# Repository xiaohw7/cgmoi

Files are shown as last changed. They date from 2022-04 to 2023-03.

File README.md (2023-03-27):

# CGMOI User Guide

## Overview

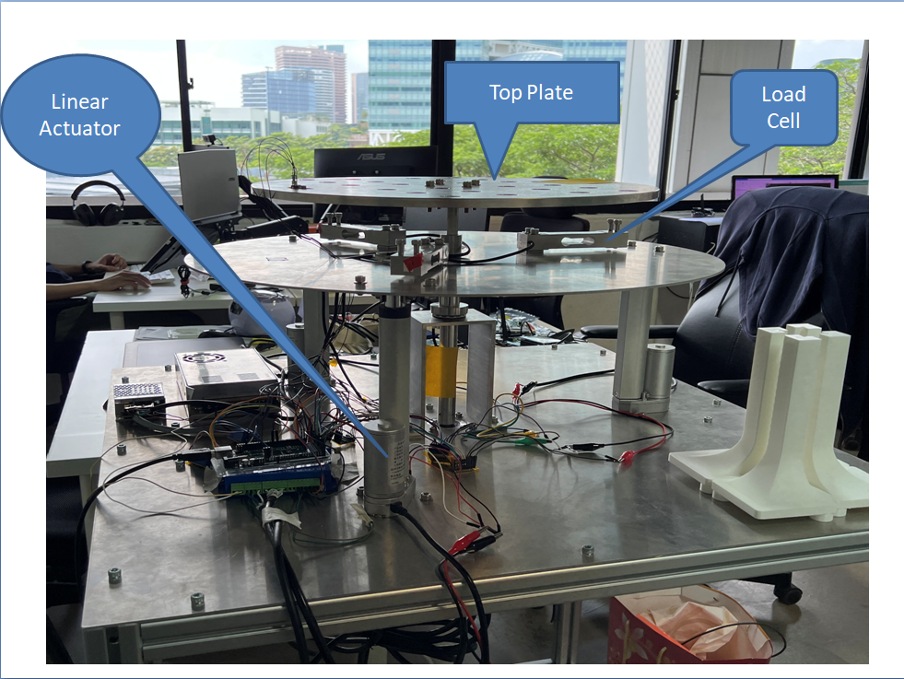
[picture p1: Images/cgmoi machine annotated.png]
cgmoi machine


The CGMOI machine is one that is capable of measuring the Centre of Gravity (CG) and Moment Of Inertia (MOI) of a nano-satellite while satellite is mounted on the top plate as shown in picture below.

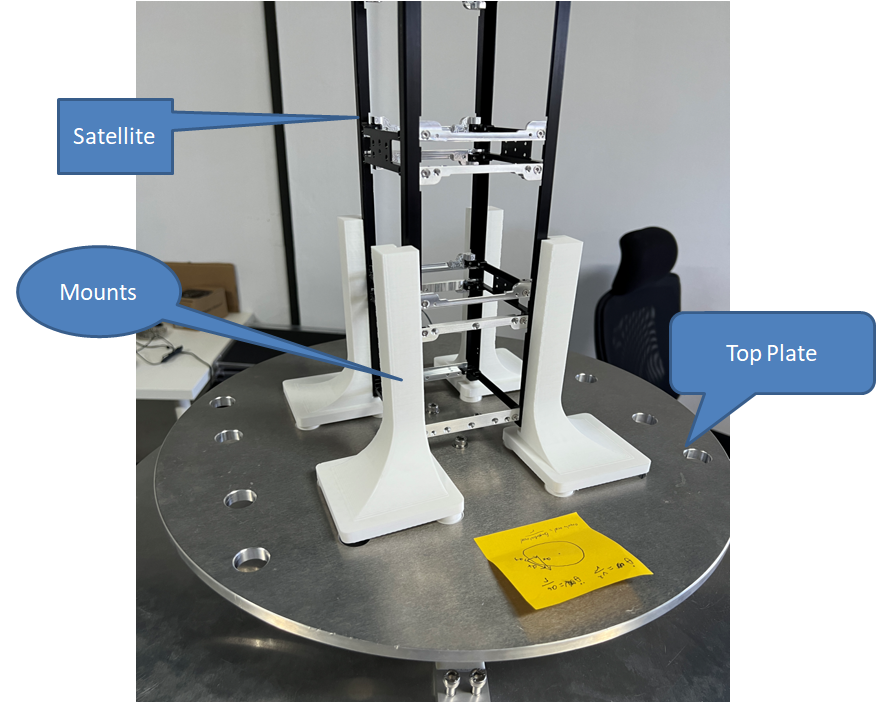
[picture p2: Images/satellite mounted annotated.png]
satellite mounted


The concept of this machine is based on [this research paper](https://github.com/xiaohw7/cgmoi/blob/main/applsci-08-00104.pdf) done by researchers from ZheJiang University. It uses 3 load cells in a circle spaced 120 degrees apart to measure CG and a gyroscope to measure acceleration which in turn can be used to obtain MOI.

The machine also includes a stepper motor that spins the top plate, and linear actuators to raise and lower the load cells in order to measure CG.

The stepper motor, linear actuator, gyroscope, load cells and other components are controlled by and wired to an Arduino mega board. The Arduino could then be plugged into a laptop running the Arduino IDE where code could be uploaded to run the CGMOI machine.

Each load cell is marked load cell 1/2/3 on the load cell itself. Linear actuator 1/2/3 correspond to load cell 1/2/3. i.e. linear actuator 1 is directly below load cell 1.

## Components of the CGMOI Machine

- HX711 analog to digital converter
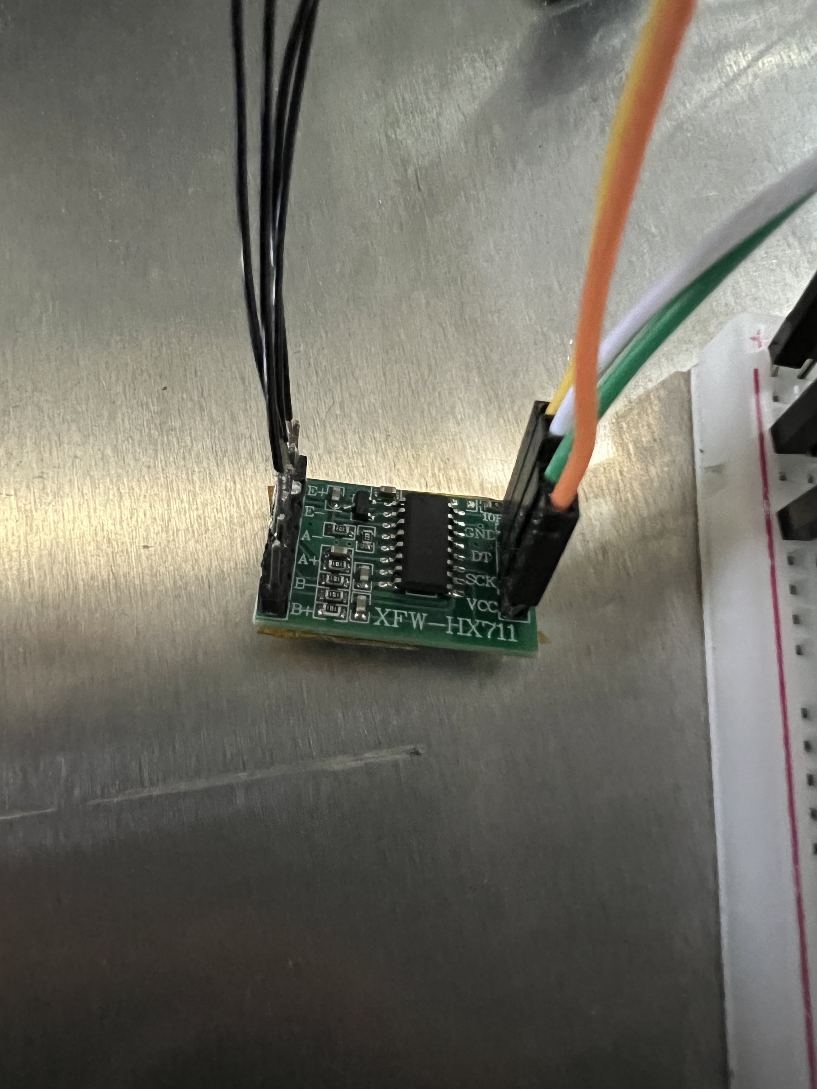
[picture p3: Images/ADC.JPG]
ADC


- Single pole double throw(SPDT) relay
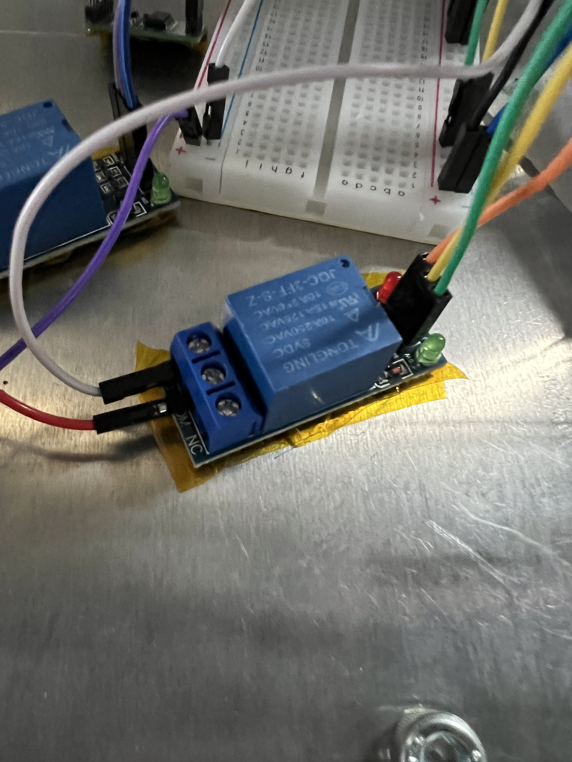
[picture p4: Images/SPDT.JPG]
spdt


- Double pole double throw(DPDT) relay
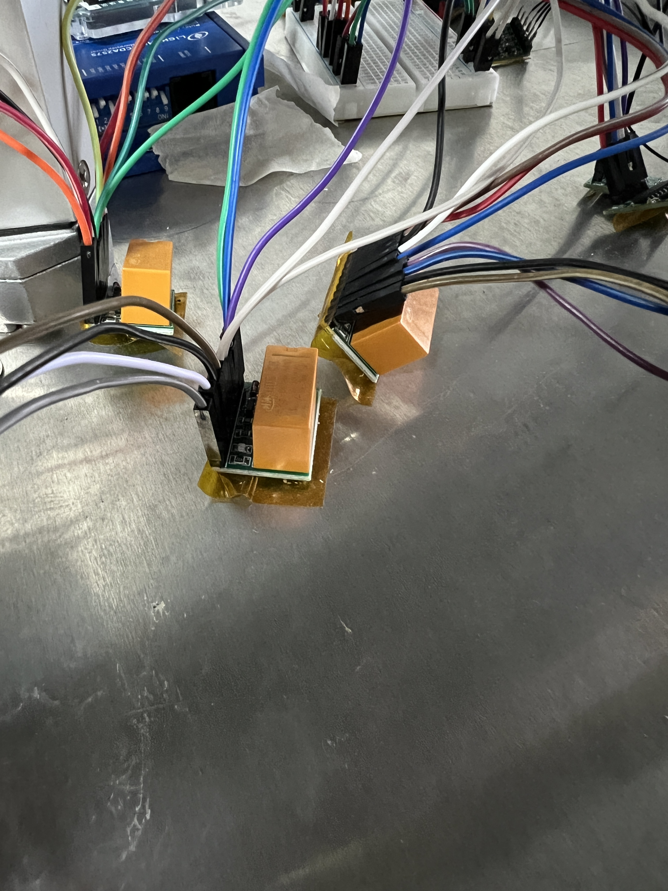
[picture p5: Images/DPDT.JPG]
dpdt


- Gyroscope
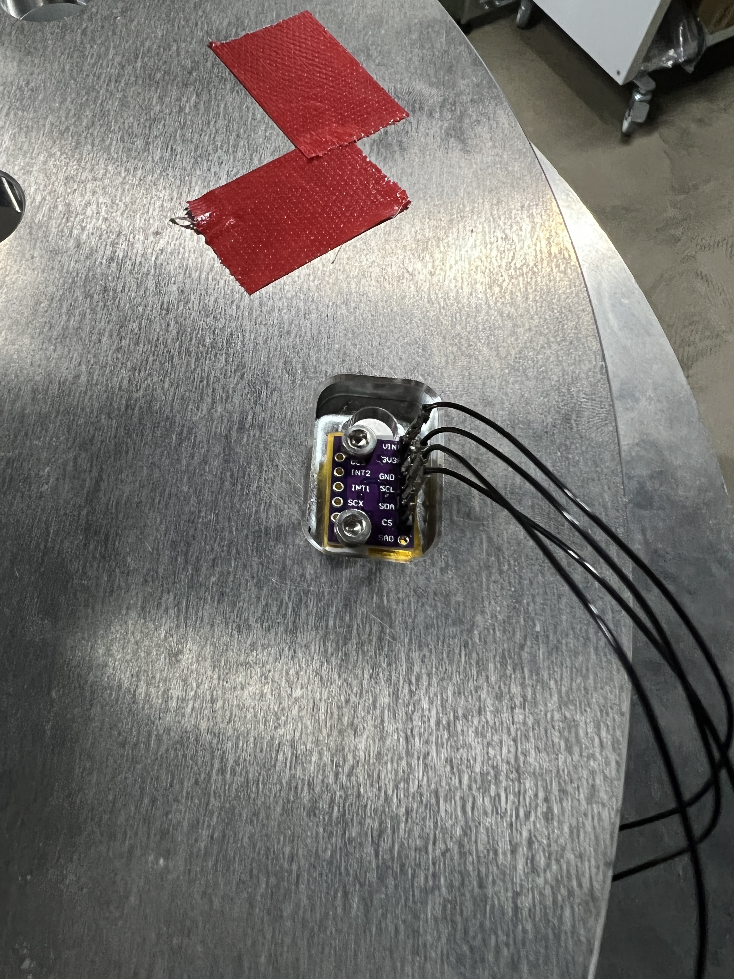
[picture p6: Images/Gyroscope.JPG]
gyro


- Power supply (12v and 36v)
power supply

- Printed circuit Board
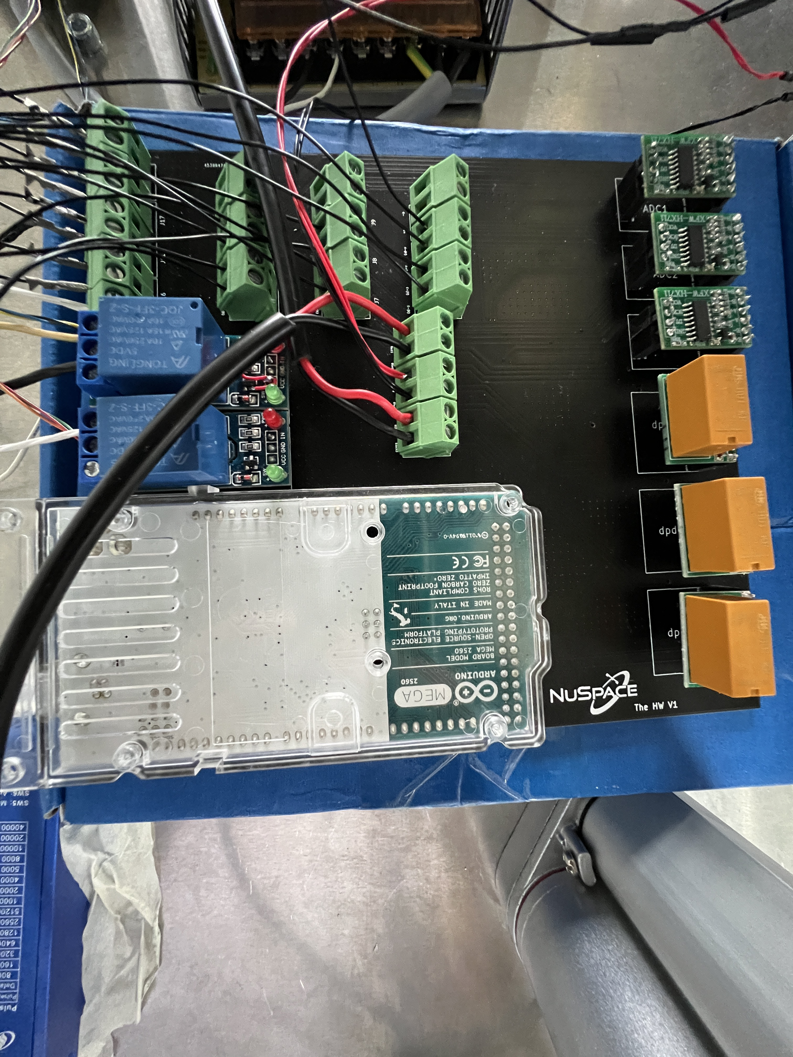
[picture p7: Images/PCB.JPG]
PCB


## How to use

1. User would have to download the following Arduino libraries:
      - [HX711_ADC](https://github.com/olkal/HX711_ADC) for the load cells
      - [hanyazou](https://github.com/hanyazou/BMI160-Arduino) for the BMI160 gyroscope
      - [AccelStepper](https://github.com/waspinator/AccelStepper) for stepper motor and stepper motor driver
      - [FreeRTOS](https://github.com/feilipu/Arduino_FreeRTOS_Library) for running Real Time Operating System on Arduino
      - [SimpleKalmanFilter](https://github.com/denyssene/SimpleKalmanFilter) for running values through a Kalman filter to reduce noisy readings

2. Upload cgmoi2.ino onto Arduino and open Serial monitor. Serial monitor to use 9600 baud. Stepper motor driver should be set to 1600 pulse/rev.

3. Code uses FreeRTOS. There will be 4 tasks, namely Rotate, Gyro, Motor, and Cg. Code will suspend Rotate, Gyro, and Motor task immediately in void setup() and Cg task will run at highest priority.

4. Code has 3 modes. Mode CG runs Cg task, reads values from load cells and output CG and mass values. Mode MOI runs Motor and Gyro tasks and outputs angular acceleration values. Mode ROTATE runs Rotate task and allows user to rotate top plate a desired number of steps in either direction.

5. After uploading code, Arduino will be running mode CG and user can see output values from load cells on Serial monitor. User can either continue with mode CG to measure CG of satellite, switch to mode MOI to measure MOI of satellite instead or switch to mode ROTATE to rotate top plate to the desired orientation.

6. Mode CG: User intends to measure CG of satellite

      * Linear actuators must be fully extended.

      * It is advisable to test each linear actuator by moving them up and down individually for 1 second before raising all three actuators completely. Refer to "Commands to send" table below for commands to move actuators individually.

      * Ensure ***screw securing removeable shaft (shown below) is removed*** before sending '9' in Serial monitor to raise linear actuators completely. Then, send '11' in serial monitor to tare load cells before mounting satellite.

      * screw securing removeable shaft

      * Directions of x and y axis are indicated on the top plate and also illustrated in "Calculations" section below.

      * To ease measuring process of CG, x and y axis on top plate must align with axis indicated in "Calculations" section below. Arrow of y axis must point directly away from load cell 1. Location of origin is the center of the top plate.

      * One way to align x and y axis is to align the marked line on the edge of the top plate with the number 1 indicated on load cell 1(marked line should be on the edge of the top plate and positioned 90 degrees counter clockwise from the gyroscope when looking from above the gyroscope mounting point). User can do so with the help of mode 3. An illustration is shown below.

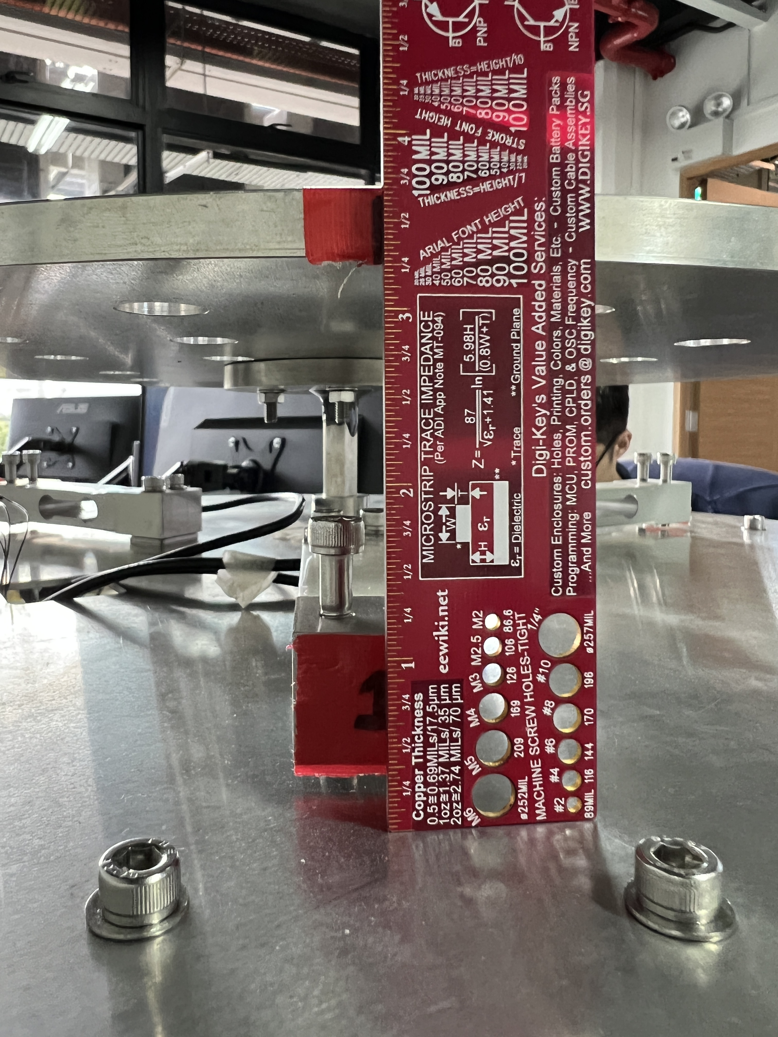
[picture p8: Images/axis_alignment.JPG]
axis alignment
      * 

      * While running task Cg, mass and CG coordinates can be read straight off the output on the Serial monitor. Refer to "Calculations" section below for x and y axis. Coordinates are in mm.

      * User can send '14' to switch to mode MOI and measure MOI of satellite.

      * User can send '16' to switch to mode ROTATE and to rotate top plate.

7. Mode MOI: user intends on measuring MOI of satellite

      * Linear actuators must be fully retracted. Send '10' while in mode CG to fully retract linear actuators.

      * Ensure screw securing removeable shaft (shown above) is secured, send '14' to switch from mode CG to mode MOI.

      * Mode MOI uses 'stepper' instance of AccelStepper class to control stepper motor.

      * Gyro and Motor tasks will run simultaneously and angular acceleration values can be read from serial monitor. Motor will spin back and forth to allow gyro to measure acceleration values. Once measurement process is finished, average acceleration will be displayed on serial monitor along with "Finish recording" message. User has 15 seconds to mount/dismount satellite before recording process starts again.

      * User should record down angular acceleration values with and without satellite mounted. Refer to "Calculations" section for the equations to obtain MOI.

      * While running mode MOI, user can also send '15' to switch to mode CG and return to reading values from load cells.

      * While running mode MOI, user can send '16' to switch to mode ROTATE to rotate top plate.

8. Mode ROTATE: user intends to rotate top plate

      * Linear actuators must be fully retracted. Send '10' while in mode CG to fully retract linear actuators.

      * Ensure screw securing removeable shaft (shown above) is secured, send '16' to switch from mode CG to mode ROTATE.

      * User can input number of steps user wishes stepper motor to turn.

      * Mode ROTATE uses 'rotate' instance of the AccelStepper class. A separate instance from the one used in mode MOI. Hence when user first uploads `cgmoi2.ino`, mode ROTATE regards the position of the stepper motor at that instant as 0 (origin). User can instruct stepper motor to rotate to a specific position that is a certain number of steps away from the origin. Positive steps are in the clockwise direction from origin while negative steps are in the counter clockwise direction from origin.

      * Note that location of origin stays the same the whole time while using the code until Arduino is refreshed. Therefore if user inputs 3000 (motor rotates 3000 steps in clockwise direction from origin) and then inputs 1000, motor would subsequently rotate 2000 steps in the counter clockwise direction and stop at the position that is 1000 steps clockwise from the origin.

      * If user uses mode ROTATE to rotate to 3000 steps clockwise, and then proceeds to use mode MOI, mode MOI will alter the position of the stepper motor but mode ROTATE will still think it is at 3000 steps clockwise. Hence if user then goes back to mode ROTATE and inputs 0, motor will rotate 3000 steps counter clockwise.

      * ***Ensure serial monitor is set to 'No line ending'.***

      * While running mode ROTATE, user can send '15' to switch to mode CG and return to reading values from load cells.

      * While running mode ROTATE, user can send '14' to switch to mode MOI and measure MOI of satellite.

Below is an illustration of how to navigate between the three modes:

***
```
            (User uploads code)
                 |       
                 |   ----------------<--------------------------   
                 |   |                                         |
                 v   v                                         |
            -->(Mode CG)------->---------------                |
            |      |                          |                |
*send '15'* |      | *send '14'*              | *send '16'     ^ *send '15'*
            ^      |                          |                |
            |      v        *send '16'        v                |
            ---(Mode MOI)--------->----(Mode ROTATE)----->------
                   ^                          |
                   |       *send '14'         |
                   -------------<--------------  
```
***

## Commands to send

|Mode |Commands that can be sent |What it does|
|-----|---|---|
|CG |Send '1' |Turn on power to linear actuators|
|CG |Send '2' |Turn off power to linear actuators|
|CG |Send '3'/'5'/'7' |Move linear actuator 1/2/3 up for 1 second|
|CG |Send '4'/'6'/'8' |Move linear actuator 1/2/3 down for 1 second|
|CG |Send '9' |Move all 3 linear actuators up fully|
|CG |Send '10' |Move all 3 linear actuators down fully|
|CG |Send '11' |Tare all load cells|
|CG |Send '12' |Turn on power to stepper motor|
|CG |Send '13' |Turn off power to stepper motor|
|CG |Send '14' |End Cg task and resume/start Gyro and Motor tasks, switch to mode MOI|
|CG |Send '16' |End Cg task and resume/start Rotate task, switch to mode ROTATE|
|MOI |Send '12' |Turn on power to stepper motor|
|MOI |Send '13' |Turn off power to stepper motor|
|MOI |Send '15' |End Gyro and Motor tasks and resume/start Cg task, switch to mode CG|
|MOI |Send '16' |End Gyro and Motor tasks and resume/start Rotate task, switch to mode ROTATE|
|ROTATE |Send '12' |Turn on power to stepper motor|
|ROTATE |Send '13' |Turn off power to stepper motor|
|ROTATE |Send '14' |End Rotate task and resume/start Gyro and Motor tasks, switch to mode MOI|
|ROTATE |Send '15' |End Rotate task and resume/start Cg task, switch to mode CG|
|ROTATE |Send steps to rotate |Motor rotate to set steps|

## Points to take note

- Before raising/lowering linear actuators, user must remember to ***remove screw securing removeable shaft***.

- When lowering top plate, user should stand by and make sure removeable shaft enters designated slot correctly.

- Before measuring CG, user to ensure that the tips of adjustable screws (shown below) on load cells are the same distance above the table top so that when top plate is resting on load cells, top plate is as flat as possible.

load cell screws

- Before measuring MOI, ensure screw securing removeable shaft is tightened to prevent any play when motor is turning.

- FreeRTOS can be buggy which causes starting position of gyroscope to shift after repeatedly using mode MOI. Hence it is recommended to position gyro chip above red tape using mode ROTATE before using mode MOI to measure angular acceleration.

- There is a tendency for SPDT relay supplying power to stepper motor to get stuck in the close position despite the LED light being off and signal sent to it to disconnect. This may be because relay is only rated for 30V while power supply is at 36V. Tapping the blue box on the relay would help to disconnect it. User can tell if power had been disconnected by observing light on stepper motor driver.

- Angular acceleration values is rather unreliable and difference while loaded and unloaded may not be easily observed. Sometimes loaded values may even be higher than unloaded values. May be due to looseness and play at the epoxy region of removeable shaft.

- First measurements of angular velocity tend to be buggy and inaccurate, hence code only starts recording values from second reading onwards.

- If load cell readings become inaccurate, try running "Calibration" example from this [github library](https://github.com/olkal/HX711_ADC) and obtain calibration values for each individual load cell and input into the code.

- If there is a need to stop measurements/linear actuators/stepper motor immediately, unplug Arduino to "Emergency Stop".

## Calculations

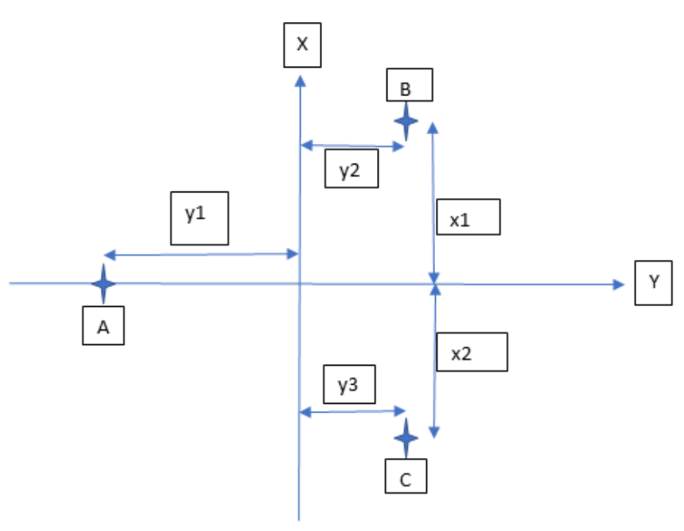
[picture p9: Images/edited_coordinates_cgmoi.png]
edited coordinates


With reference to image above, points A,B,C correspond to load cell 1,2,3 respectively. Load cell numbers are marked on load cells.

1. Finding Mass

      * Pa = m4 - m1
      * Pc = m6 - m3
      * Pb = m5 - m2
      * Mass of satellite, M = Pa + Pb + Pc  
      * m1, m2 and m3 are weights of fixture tools and platform on load cell A, B and C respectively.
      * m4, m5 and m6 are weights of fixture tools, platform and satellite on load cell A, B and C respectively.
      * Pa, Pb and Pc are satellite weights on load cell a, b and c respectively.
      * Code outputs overall mass of satellite in grams.

2. Finding Centre of Gravity

      * Y-coordinate, yG = [Pb(y2) + Pc(y3) − Pa(y1)]/M
      * X-coordinate, xG = [Pb(x1) − Pc(x2)]/M
      * y1, y2, y3 are distances of points A, B, ad C from y-axis respectively. y1 = 206mm, y2 and y3 = 103mm
      * x1, x2, are distances of point B and C from x-axis. x1 and x2 = 178.4mm
      * Lengths are calculated using values from [load cell plate drawing](https://github.com/xiaohw7/cgmoi/blob/main/M02_load%20cell%20plate_drawing.pdf) and [load cell data sheet](https://github.com/xiaohw7/cgmoi/blob/main/M02_load%20cell%20plate_drawing.pdf).
      * To obtain z-coordinate of CG, rotate satellite by 90 degrees and undergo same calculations to obtain z-coordinate.
      * Code outputs coordinate of CG with reference to axis above and in millimeters.

3. Finding Moment Of Inertia

      * moi_eqn

      * Use equation above to obtain J1. Where J1 is MOI of satellite. J0 is MOI of fixture tools which can be obtained from solid works. Shown in picture below, J0 in the vertical axis, taken at output coordinate system with center of top plate as origin, is ***19113908.45 grams * square millimeters***.
      * MOI_topplate
      *  Referring again to equation to obtain J1, w0 is angular velocity at time t without satellite. w’0 is angular velocity at time t with satellite. t1 and t2 are time at which angular velocity w0 and w’0 is taken respectively.
      * Thus it is observed that the fraction in the equation is angular acceleration without satellite mounted divided by angular acceleration with satellite mounted.
      * Code outputs angular acceleration values in degrees/sec^2 which can then be used to calculate J0.

      * Rotating about X-axis of satellite will result in JX

      * Rotating about Y-axis of satellite will result in JY

      * Rotating about Z-axis of satellite will result in JZ

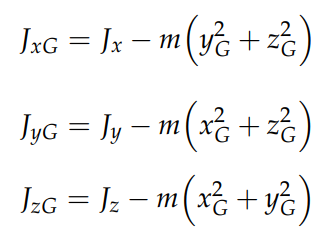
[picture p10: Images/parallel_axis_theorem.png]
parallel axis theorem
      * 

      * Above equation uses parallel axis parallel axis theorem to correct MOI vector with reference to the CG and find vector of MOI. JxG, JyG, JzG are the MOI in x, y, and z direction respectively.

## Areas for improvement

1. Values for angular acceleration can vary substantially leading to inaccurate and imprecise values of MOI.

     * One way to improve is to move designated mounting place of BMI160 chip to the center of the top plate. This way Arduino can use raw values of angular velocity measured by the gyroscope in the MOI equation instead of having to measure linear acceleration values and then subject them to a series of calculations to obtain angular acceleration.

     * Another way is to decrease the play in the removeable shaft especially at the spot with Epoxy where the shaft connects with the flat plate.

2. Torque of stepper motor varies with speed and is difficult to control. This may lead to inaccurate values of MOI when torque applied while top plate is loaded vs when it is unloaded is different.

     *  Potential way to improve is to change to motor to a simple DC motor that outputs constant torque every time it accelerated top plate from rest regardless of whether top plate is loaded.

3. PCB enclosure was not fully printed because filament kept breaking during the print. 2 halves of the enclosure were used as a makeshift PCB enclosure with one end of sawn open to create opening for wires. Also, slot for PCB to sit in and the width of the enclosure was too narrow for PCB to fit and required a lot of filing. Even then PCB had difficulty fitting into the slot.

      * To increase probability of success of subsequent prints, opening of PCB enclosure should be widened by 1-2mm. Height of slot meant for PCB should be increased by 1mm. Walls of enclosure can also be made thinner for a faster print. And use filament that's less likely to break during print.

## Instructions
Below are instructions on how to set up each individual component of the CGMOI machine, links to each component's datasheet, as well as some notes I made on the my experiences.

### HX711 ADC and load cells:

- Refer to [this link](https://makersportal.com/blog/2019/5/12/arduino-weighing-scale-with-load-cell-and-hx711) for instructions on how to connect load cell to HX711 to Arduino. All 3 load cells can share a common power and ground connection.

- Download library at [github](https://github.com/olkal/HX711_ADC) for examples on calibrating and reading values from multiple load cells.

- To calibrate load cell, connect Arduino to an individual load cell through HX711 and run “Calibration” example. Follow instructions on the serial monitor and record down “calibration value”.  Do this for every individual load cell.

- Use `HX711_script3.ino` to read all 3 load cells. Input “calibration values” of each respective load cell into the code. Weight reading is taken 10 times with 0.05sec intervals and average weight on each load cell is obtained. Calculations are then made with the average weights. Run the code and read values of weight and coordinates of CG from serial monitor.

- Send “t” on serial monitor to tare load cells immediately.

- Reading is in grams. CG units are in mm.

- [HX711 data sheet](https://onedrive.live.com/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)

- [Load cell data sheet](https://onedrive.live.com/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)

### BMI 160 Gyro:

- Refer to [hanyazou's github](https://github.com/hanyazou/BMI160-Arduino) for instructions to connect to gyro sensor. Download library at the same website. Use example `Gyro` example or `bmi_160_gyro_script.ino` to read from sensor. Switch example code to I2C mode.

- Another library that can read from gyro is [DFRobot](https://github.com/DFRobot/DFRobot_BMI160#installation). Download the library and use `accelgyro` example for both accelerometer and gyroscope readings.

- `bmi_160_gryo_script2.ino` takes `accelgyro` example from DFRobot library and modifies it to obtain net acceleration from x and y axis using Pythagoras theorem. Measurements are taken every 0.1 seconds and the average of 10 readings are calculated. Acceleration is converted from g to degrees/sec^2.

- `bmi_160_gryo_script3.ino` modifies `bmi_160_gyro_script.ino` to get net acceleration using Pythagoras theorem on the x an y axis acceleration values.

- Net acceleration is then divided by radius (distance from gyro to center of top plate) to obtain angular acceleration in radians which is then converted to degrees.

- Sensor is to use 3.3v from Arduino.

- Helpful links at [arduino projects](http://www.arduinoprojects.net/sensor-projects/using-bmi160-sensor-arduino-uno.php) and [sparkfun.](https://learn.sparkfun.com/tutorials/gyroscope/all)

- [BMI 160 datasheet](https://onedrive.live.com/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)

### Linear actuator with relay:

- One SPDT relay to be used as overall power switch to linear actuators. 3 DPDT relays to be used as switches for each individual actuator and to be connected in a way to allow current to flow in both direction so as to enable actuator to extend and retract.

- Helpful links for SPDT relay can be found at [circuit basics](https://www.circuitbasics.com/setting-up-a-5v-relay-on-the-arduino/) and [last minute engineers](https://lastminuteengineers.com/one-channel-relay-module-arduino-tutorial/).

- Wiring for DPDT relay to be able to reverse current polarity to actuators can be found at [digikey](https://forum.digikey.com/t/polarity-reversal-using-a-dpdt-switch/626/4).

- Wiring:

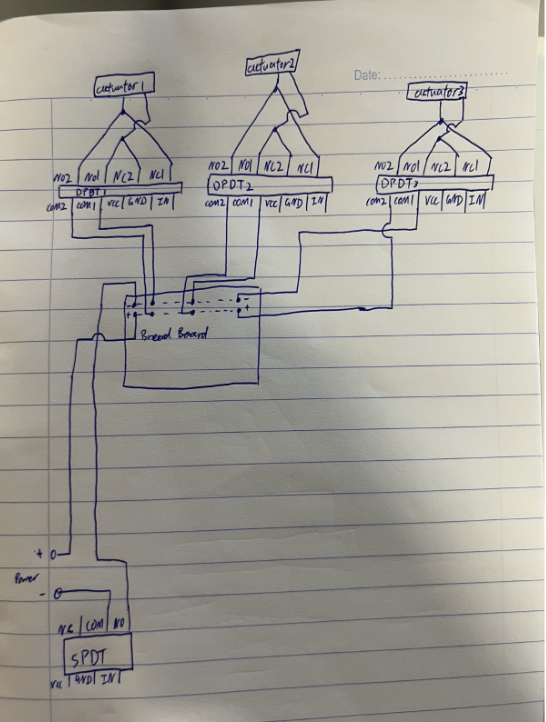
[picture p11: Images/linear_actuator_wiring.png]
linear actuator wiring


- Above picture shows wiring of linear actuators with relays.

- VCC and GND of all relays are connected to 5V and GND of Arduino through breadboard.

- For each DPDT relay, NO2 and NC1 should be connected to the black wire of actuator while NO1 and NC2 should be connected to the red wire of actuator.

- Use `linear_actuator_script.ino` to control the actuators by sending commands through serial monitor.

|Commands that can be sent |What it does|
|---|---|
|Send '1'|Power on|
|Send '2'|Power off|
|Send '3'/'5'/'7'|Move actuator 1/2/3 up for 1 sec|
|Send '4'/'6'/'8'|Move actuator 1,2,3 down for 1 sec|
|Send '9'|Move all 3 actuators up completely|
|Send '10'|Move all 3 actuators down completely|

- Linear actuator to use 12V from power supply.

- [Linear actuator data sheet](https://onedrive.live.com/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)

- [spdt relay datasheet](https://onedrive.live.com/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)

- [dpdt relay datasheet](https://datasheetspdf.com/datasheet/HK19F-DC5V.html)

### LICHUAN LCDA257S stepper motor driver and stepper motor:

- See [dronebotworkship](https://dronebotworkshop.com/big-stepper-motors/) to get an overview on stepper drivers and motors.

- See [makersguides](https://www.makerguides.com/tb6600-stepper-motor-driver-arduino-tutorial/) for example code and wiring.

- Number of pulses per round can be adjusted by referring to table on the driver.

- Download AccelStepper library from [github](https://github.com/waspinator/AccelStepper).

- In AccelStepper library, speed is in steps/sec, Acceleration is in steps/sec2, position is in number of steps.

- `Stepper_motor_driver.ino` controls stepper motor directly while `Stepper_motor_driver2.ino` uses AccelStepper library to control motor.

- Another way of accelerating stepper motor is do gradually quicken pulses sent to motor (ramping). Code is in `Stepper_motor_driver3.ino`.

- Another sketch based on is conjured up Stepper_motor_driver2.ino is conjured up with the intention of enabling user to input number of steps the user wishes the stepper motor to rotate. Code is in `rotate_topplate.ino`. Starting position of stepper motor when user first uploads the code is always regarded as the origin. User can instruct stepper motor to rotate to a specific position that is a certain number of steps away from the origin. Positive steps are in the clockwise direction from the origin while negative steps are in the counter clockwise direction from the origin. Note that location of origin stays the same the whole time while using the code and only changes if user resets the Arduino or uploads the code again.

- There was a problem of code running twice for one input. Problem was solved by setting serial monitor to 'No line ending'. Code is in `rotate_topplate.ino`.

- Stepper motor to use 36V from power supply.

- [Stepper motor driver datasheet](https://onedrive.live.com/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)

- [Stepper motor datasheet](https://onedrive.live.com/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)

### Putting it together (Gyro and Motor):

- Function to control movement of stepper motor in AccelStepper library is blocking, thus we use FreeRTOS on Arduino, Gyro and Motor can run and read data simultaneously. FreeRtos library can be found at [github](https://github.com/feilipu/Arduino_FreeRTOS_Library).

- `moi.ino`(`Stepper_motor_driver2.ino` + `bmi_160_gryo_script3.ino`) uses FreeRTOS and AccelStepper library to run motor and gyro simultaneously.

- Alternatively, we can use Pulse Width Modulation to send pulses to stepper motor. analogWrite() function output a PWM signal to stepper motor and is not a blocking function. Hence can collect data from gyro immediately after starting stepper motor.

- Code to toggle PWM frequencies in Arduino can be found  [here](https://www.etechnophiles.com/how-to-change-pwm-frequency-of-arduino-mega/).

- Take note: code to change PWM frequency to 62500 Hz changes delay() function such that delay(1000000) now is approximately 15 sec.

- Also, offset values are recorded so as to account for gyro not being completely flat. Code can be found in `moi2.ino` (using PWM to control stepper motors + `bmi_160_gryo_script2.ino`).

- However, Gyro still experiences large amount of noise. To reduce noise, gyro code include a digital low pass filter in the code from [hanyazou's github](https://github.com/hanyazou/BMI160-Arduino).  Also, a simple Kalman Filter found on [github] (https://github.com/denyssene/SimpleKalmanFilter) is added into the code which decreased standard variation when top plate is stationary as well as when it is moving, the final angular acceleration value is put through the filter.  

- Using FreeRTOS and PWM with altered frequency of 31372.55 Hz, a graph of angular acceleration against time is plotted through the acceleration and deceleration of the stepper motor.  It is observed that there is a very sharp peak acceleration when stepper motor accelerates and acceleration. Hence the gyro will measure acceleration values throughout the motor’s acceleration and the code will record down the peak acceleration value.

- Gyroscope sample rate is changed from 200Hz to 1600Hz so as to increase accuracy. Peak acceleration values are put in an array and after a certain number or recordings, mean and standard deviation are calculated from the peak values in array. Code is in `moi3.ino` (using PWM to control stepper motors + `bmi_160_gryo_script3.ino`).

- However, peak acceleration values tend to vary substantially (sometimes up to 60%). We can use FreeRTOS to run gyro and motor with AccelStepper library simultaneously. Motor will accelerate at a set acceleration and gyro can measure average acceleration during that time.

- 3 tasks are created, namely Control, Motor and Gyro. Control task will run with highest priority and will first suspend Gyro and Motor task. Purpose of Control task is to take commands from serial monitor and start Gyro and Motor task to begin recording of values.

- While motor task is causing motor to accelerate, Gyroscope task will run and read acceleration values with each loop. Average acceleration is obtained by dividing total acceleration by number of loops variable loopCount. Average acceleration values are added to an array and a subsequent average is obtained at the end of a set number of recordings.

- When switching from Control task to Gyro and Motor task, first reading is buggy and inaccurate and hence not added to the array. Only 2nd reading onwards are added to the array. loopCount can also be used to limit gyro’s recording to the acceleration process of the motor and not both acceleration and deceleration.

- A new problem arise when load is put on top plate, average acceleration is observed to increase instead of decrease due to majority of acceleration values becoming higher despite peak acceleration becoming lower. This may be due to the usage of AccelStepper library which allows motor to draw more current to maintain set acceleration. Solution is to max out setAcceleration() and setMaxSpeed() functions so that motor could not draw any additional current and to set dip switches on the side of the stepper motor driver to 1600 pulses/round. Code is in `moi4.ino` (modified from `moi.ino`).

### Putting it together (Linear Actuator and Load Cells):
- Refer to above instructions “Linear actuator with relay” for instructions on how to operate linear actuators. Once Arduino is on, load cells are already reading weight values and calculating CG.

- Linear actuators should be tested first by moving each actuator up and down.

- Marked line at the edge of top plate should be aligned with number 1 indicated on loadcell 1 so that the axis indicated on the top plate correspond to calculations using the 3 load cells. Marked line should be 90 degrees counter clockwise from gyroscope when looking from the top view.

- Linear actuators should be extended all the way to measure weight of satellite. Satellite should be placed on the top plate after actuators fully extend and taring load cells. Wait for “Tare load cell 1 / 2 / 3 complete” message. User should also tare load cells after each measurement.

- Arduino mega is able to support all 3 load cells and the 4 relays hence all 7 components will share the same VCC and GND through breadboard. Code is in `cg.ino` (`linear_actuator_script.ino` + `HX711_script3.ino`).

### Putting it together (CG and MOI):

- Code uses FreeRTOS. There will be 3 tasks, namely Gyro, Motor and Cg. Code will suspend Gyro and Motor task in void setup(). Cg will run at highest priority.

- While running task Cg, user can control linear actuators and read values from load cells. User can send command to suspend Cg task and resume Gyro and Motor task in order to start obtaining angular acceleration values. While running Gyro and Motor task, user can also send command to suspend Gyro and Motor task and resume Cg task to return to reading values from linear actuators. Code is in `cgmoi.ino`(`moi4.ino` + `cg.ino`).

- To facilitate more accurate and easier measurements of CG, another task, based on `rotate_topplate.ino`, is added to the code. Rotate task uses a separate instance of AccelStepper class from the one used in Motor task and allows user to control stepper motor and rotate top plate a set number of steps in either direction to facilitate alignment of top plate before raising linear actuators to measure CG. New code has 4 tasks, namely Gyro, Motor, Cg, and Rotate. Code is in `cgmoi2.ino`.

### Putting it together (Printed Circuit Board):

- The Arduino Mega board along with relays and ADCs are to be stacked on top of the PCB.

- Wiring of components of CGMOI machine such as load cells, gyro, ADC to Arduino on PCB will be done with screw terminals soldered onto PCB.

- Female headers will be soldered on to PCB so that relays and ADCs can be stacked on PCB.

- Male headers will be soldered on to PCB so that Arduino Mega can be stack on the PCB.

- PCB along with its components would be put into a PCB encloser with opening for wires to connect to other components.

- PCB was designed using KiCad and the files can be found [here](https://github.com/xiaohw7/cgmoi/tree/main/pcb/CGMOI).

- PCB encloser is designed using solidworks and to be 3D printed. Design of encloser is based on [this PCB encloser](https://www.lazada.sg/products/extruded-pcb-aluminum-box-black-enclosure-electronic-project-case-80x160x170mm-i2083438345-s11541324037.html)

- PCB CAD files can be found on [Onedrive](https://onedrive.live.com/?authkey=%21AlhODXygXZWnhUQ&id=8E16A592663A6%2154244&cid=0008E16A592663A6)

- [Screw terminal to be used](https://www.digikey.sg/en/products/detail/w%C3%BCrth-elektronik/691211720002/2060530 )

- [Female headers to be used](https://www.digikey.sg/en/products/detail/samtec-inc/SSW-101-01-G-D/6691946 )

- [Male headers to be used](https://www.digikey.sg/en/products/detail/sullins-connector-solutions/PREC003SAAN-RC/2774851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)

- There was an error in the PCB design regarding dpdt 2 and dpdt 3. The input, vcc, com1, and com2 pins meant for dpdt2 has been wrongly placed at dpdt3 and vice versa. Fortunately, all dpdt relays share the same vcc, com1, and com2 so technically there is no impact there. As for the input pins, simply changing the Arduino code such that input pin of dpdt 2 is now the input pin of dpdt 3 and vice versa has solved the problem.

- 12v power supply for linear actuators do not function properly when connected to PCB. When linear actuators are turned on, 12v power supply stutters and its LED light flicker on and off. As a result, linear actuators also stutter. Actuators are able to function normally when benchtop power supply is connected to PCB. Actuators are also able to function normally when 12v power supply is connected to breadboard. This occurrence seems to be due to the start-up current required by 3 linear actuators being too high for the 12v power supply when connected to PCB. The solution is to lower the output of the 12v power supply to roughly 10.5v. This decreased the start-up current that 3 linear actuators require to a manageable amount for the 12v power supply allowing it to continue supplying power to move the actuators.

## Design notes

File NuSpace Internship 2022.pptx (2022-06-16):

## NuSpace Internship (Feb – June 2022)

What did I do?

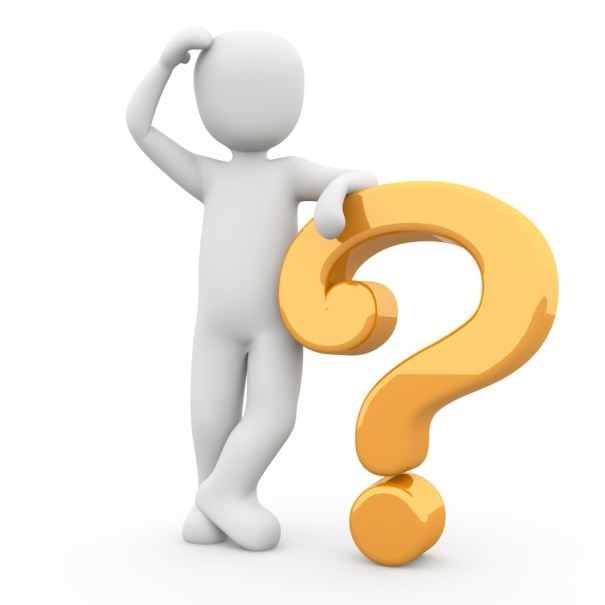
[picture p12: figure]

## Main Mission: CGMOI machine

- Integrated SPDT, DPDT relays and Arduino Mega to allow for reversible current supplied to linear actuators
- Integrated 3 ADCs with 3 load cells and Arduino Mega to obtain mass and CG coordinates.
- Set up a gyroscope with Arduino Mega to measure angular acceleration of rotation in order to calculate MOI.
- Set up stepper motor, stepper motor driver and Arduino Mega to provide constant torque when measuring MOI.

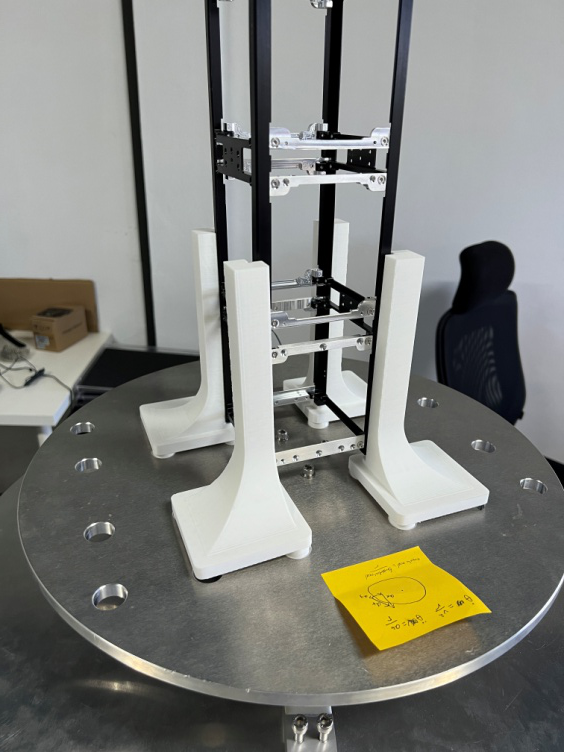
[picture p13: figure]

## Main Mission: CGMOI machine

- Set up the power supply for the machine.
- Designed and wrote an Arduino script with FreeRTOS to manage all the aforementioned components.
- Learned KiCad and designed a PCB to stack ADCs, relays and Arduino Mega.
- Picked up soldering to make wires and solder pins on PCB.
- Learned SOLIDWORKS and designed a PCB enclosure which was then 3D printed.

## SIDE QUESTS

- Taught a group of 20 CJC students about the basics of Python programming
- Participated in the assembly of the clean room
- Contributed to the assembly process of a nano-satellite by stripping and crimping wires
- Learned how to use a logic analyzer

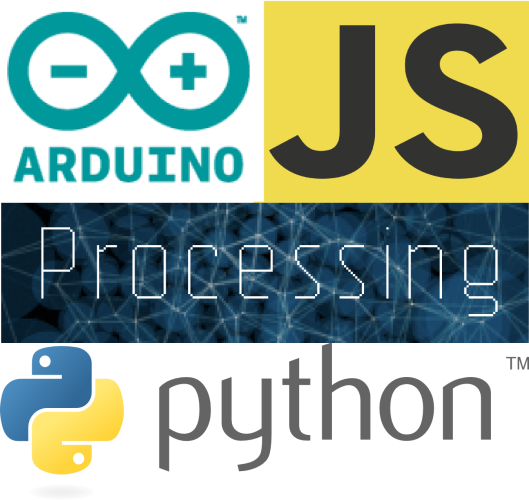
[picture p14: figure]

## SIDE QUESTS

- Create GitHub repository
- Write readme using markdown
- Learned about task manager

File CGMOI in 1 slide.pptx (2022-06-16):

## CGMOI in 1 slide

Upload `cgmoi2.ino` to Arduino, open Serial monitor (9600 baud)

Mode CG:
Read CG and mass, raise/lower actuators

Legend:
Red: Send ’14’
Green: Send ’15’
Blue: Send ’16’
Purple: Do nothing

Mode MOI: Read angular acceleration values

Mode ROTATE: Input steps and
rotate top plate

## JK 1 more slide

- Refer to readme for more details and troubleshooting.

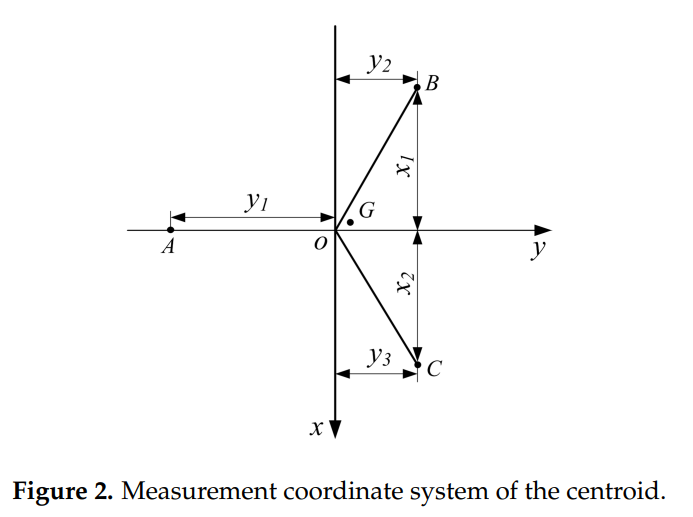
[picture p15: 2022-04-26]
Images/coordinates cgmoi.png

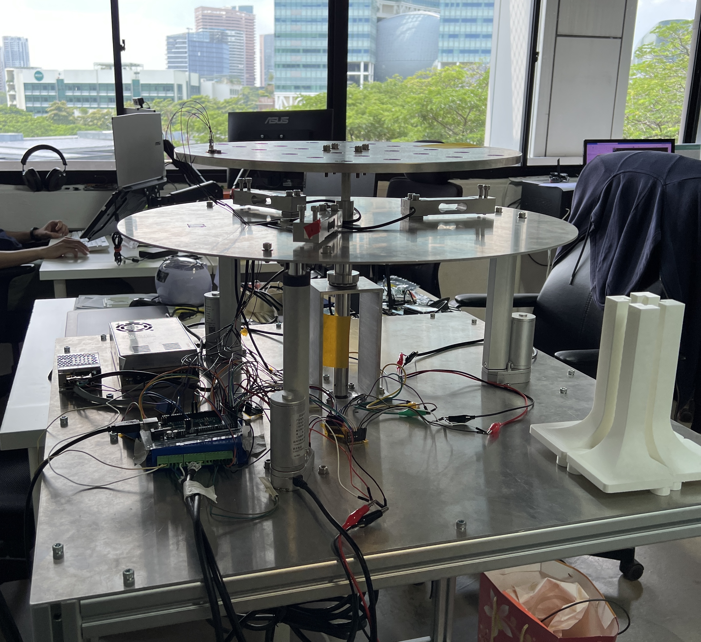
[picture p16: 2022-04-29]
Images/cgmoi_machine.jpg

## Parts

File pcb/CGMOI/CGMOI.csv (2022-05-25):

Source: | C:\Users\duc\OneDrive\Documents\KiCad\CGMOI\CGMOI.kicad_sch
Date: | 5/25/2022 2:02:56 PM
Tool: | Eeschema (6.0.2)
Generator: | C:\Program Files\KiCad\6.0\bin\scripting\plugins/bom_csv_grouped_by_value_with_fp.py
Component Count: | 81
Ref | Qnty | Value | Cmp name | Footprint | Description | Vendor
J1, | 1 | ADC1E+/- | Screw_Terminal_01x02 | cgmoi:screw terminal | Generic screw terminal, single row, 01x02, script generated (kicad-library-utils/schlib/autogen/connector/)
J2, | 1 | ADC1A-/+ | Screw_Terminal_01x02 | cgmoi:screw terminal | Generic screw terminal, single row, 01x02, script generated (kicad-library-utils/schlib/autogen/connector/)
J3, | 1 | ADC1B-/+ | Screw_Terminal_01x02 | cgmoi:screw terminal | Generic screw terminal, single row, 01x02, script generated (kicad-library-utils/schlib/autogen/connector/)
J4, | 1 | ADC2E+/- | Screw_Terminal_01x02 | cgmoi:screw terminal | Generic screw terminal, single row, 01x02, script generated (kicad-library-utils/schlib/autogen/connector/)
J5, | 1 | ADC2A-/+ | Screw_Terminal_01x02 | cgmoi:screw terminal | Generic screw terminal, single row, 01x02, script generated (kicad-library-utils/schlib/autogen/connector/)
J6, | 1 | ADC2B-/+ | Screw_Terminal_01x02 | cgmoi:screw terminal | Generic screw terminal, single row, 01x02, script generated (kicad-library-utils/schlib/autogen/connector/)
J7, | 1 | ADC3E+/- | Screw_Terminal_01x02 | cgmoi:screw terminal | Generic screw terminal, single row, 01x02, script generated (kicad-library-utils/schlib/autogen/connector/)
J8, | 1 | ADC3A-/+ | Screw_Terminal_01x02 | cgmoi:screw terminal | Generic screw terminal, single row, 01x02, script generated (kicad-library-utils/schlib/autogen/connector/)
J9, | 1 | ADC3B-/+ | Screw_Terminal_01x02 | cgmoi:screw terminal | Generic screw terminal, single row, 01x02, script generated (kicad-library-utils/schlib/autogen/connector/)
J10, | 1 | ActuatorPower12V+/- | Screw_Terminal_01x02 | cgmoi:screw terminal | Generic screw terminal, single row, 01x02, script generated (kicad-library-utils/schlib/autogen/connector/)
J11, | 1 | MotorDir/Pulse | Screw_Terminal_01x02 | cgmoi:screw terminal | Generic screw terminal, single row, 01x02, script generated (kicad-library-utils/schlib/autogen/connector/)
J12, | 1 | actuator1Black/Red | Screw_Terminal_01x02 | cgmoi:screw terminal | Generic screw terminal, single row, 01x02, script generated (kicad-library-utils/schlib/autogen/connector/)
J13, | 1 | actuator2Black/Red | Screw_Terminal_01x02 | cgmoi:screw terminal | Generic screw terminal, single row, 01x02, script generated (kicad-library-utils/schlib/autogen/connector/)
J14, | 1 | actuator3Black/Red | Screw_Terminal_01x02 | cgmoi:screw terminal | Generic screw terminal, single row, 01x02, script generated (kicad-library-utils/schlib/autogen/connector/)
J15, | 1 | GyroSCL/SDA | Screw_Terminal_01x02 | cgmoi:screw terminal | Generic screw terminal, single row, 01x02, script generated (kicad-library-utils/schlib/autogen/connector/)
J16, | 1 | MotorGNDPulse/Dir | Screw_Terminal_01x02 | cgmoi:screw terminal | Generic screw terminal, single row, 01x02, script generated (kicad-library-utils/schlib/autogen/connector/)
J17, | 1 | Gyro+/- | Screw_Terminal_01x02 | cgmoi:screw terminal | Generic screw terminal, single row, 01x02, script generated (kicad-library-utils/schlib/autogen/connector/)
pin1, | 1 | dpdt1+ | pin | cgmoi:pin
pin2, | 1 | dpdt2+ | pin | cgmoi:pin
pin3, | 1 | dpdt3+ | pin | cgmoi:pin
pin4, | 1 | dpdt1- | pin | cgmoi:pin
pin5, | 1 | dpdt2- | pin | cgmoi:pin
pin6, | 1 | dpdt3- | pin | cgmoi:pin
pin7, | 1 | spdtActuator+ | pin | cgmoi:pin
pin8, | 1 | spdtMotor+ | pin | cgmoi:pin
pin9, | 1 | spdtActuator- | pin | cgmoi:pin
pin10, | 1 | spdtMotor- | pin | cgmoi:pin
pin17, | 1 | ADC1+ | pin | cgmoi:pin
pin18, | 1 | ADC2+ | pin | cgmoi:pin
pin19, | 1 | ADC3+ | pin | cgmoi:pin
pin20, | 1 | ADC1- | pin | cgmoi:pin
pin21, | 1 | ADC2- | pin | cgmoi:pin
pin22, | 1 | ADC3- | pin | cgmoi:pin
pin23, | 1 | ADC1DT | pin | cgmoi:pin
pin24, | 1 | ADC1SCK | pin | cgmoi:pin
pin25, | 1 | ADC2DT | pin | cgmoi:pin
pin26, | 1 | ADC2SCK | pin | cgmoi:pin
pin27, | 1 | ADC3DT | pin | cgmoi:pin
pin28, | 1 | ADC3SCK | pin | cgmoi:pin
pin32, | 1 | actuator1Com2 | pin | cgmoi:pin
pin33, | 1 | actuator2Com2 | pin | cgmoi:pin
pin34, | 1 | actuator3Com2 | pin | cgmoi:pin
pin36, | 1 | actuator1Com1 | pin | cgmoi:pin
pin37, | 1 | actuator2Com1 | pin | cgmoi:pin
pin38, | 1 | actuator3Com1 | pin | cgmoi:pin
pin39, | 1 | dpdt1NO2 | pin | cgmoi:pin
pin40, | 1 | dpdt1NC1 | pin | cgmoi:pin
pin42, | 1 | dpdt1NO1 | pin | cgmoi:pin
pin43, | 1 | dpdt1NC2 | pin | cgmoi:pin
pin45, | 1 | dpdt2NO2 | pin | cgmoi:pin
pin46, | 1 | dpdt2NC1 | pin | cgmoi:pin
pin48, | 1 | dpdt2NO1 | pin | cgmoi:pin
pin49, | 1 | dpdt2NC2 | pin | cgmoi:pin
pin51, | 1 | dpdt3NO2 | pin | cgmoi:pin
pin52, | 1 | dpdt3NC1 | pin | cgmoi:pin
pin54, | 1 | dpdt3NO1 | pin | cgmoi:pin
pin55, | 1 | dpdt3NC2 | pin | cgmoi:pin
pin57, | 1 | ADC1E+in | pin | cgmoi:pin
pin59, | 1 | ADC1E-in | pin | cgmoi:pin
pin61, | 1 | ADC1A-in | pin | cgmoi:pin
pin63, | 1 | ADC1A+in | pin | cgmoi:pin
pin65, | 1 | ADC1B-in | pin | cgmoi:pin
pin67, | 1 | ADC1B+in | pin | cgmoi:pin
pin69, | 1 | ADC2E+in | pin | cgmoi:pin
pin71, | 1 | ADC2E-in | pin | cgmoi:pin
pin73, | 1 | ADC2A-in | pin | cgmoi:pin
pin75, | 1 | ADC2A+in | pin | cgmoi:pin
pin77, | 1 | ADC2B-in | pin | cgmoi:pin
pin79, | 1 | ADC2B+in | pin | cgmoi:pin
pin81, | 1 | ADC3E+in | pin | cgmoi:pin
pin83, | 1 | ADC3E-in | pin | cgmoi:pin
pin85, | 1 | ADC3A-in | pin | cgmoi:pin
pin87, | 1 | ADC3A+in | pin | cgmoi:pin
pin89, | 1 | ADC3B-in | pin | cgmoi:pin
pin91, | 1 | ADC3B+in | pin | cgmoi:pin
pin93, | 1 | spdtActuatorIn | pin | cgmoi:pin
pin94, | 1 | dpdt1In | pin | cgmoi:pin
pin95, | 1 | dpdt2In | pin | cgmoi:pin
pin96, | 1 | dpdt3In | pin | cgmoi:pin
pin97, | 1 | spdtMotorIn | pin | cgmoi:pin
XA1, | 1 | Arduino_Mega2560_Shield | Arduino_Mega2560_Shield | cgmoi:Arduino_Mega2560_Shield | Shield for Arduino Mega 2560

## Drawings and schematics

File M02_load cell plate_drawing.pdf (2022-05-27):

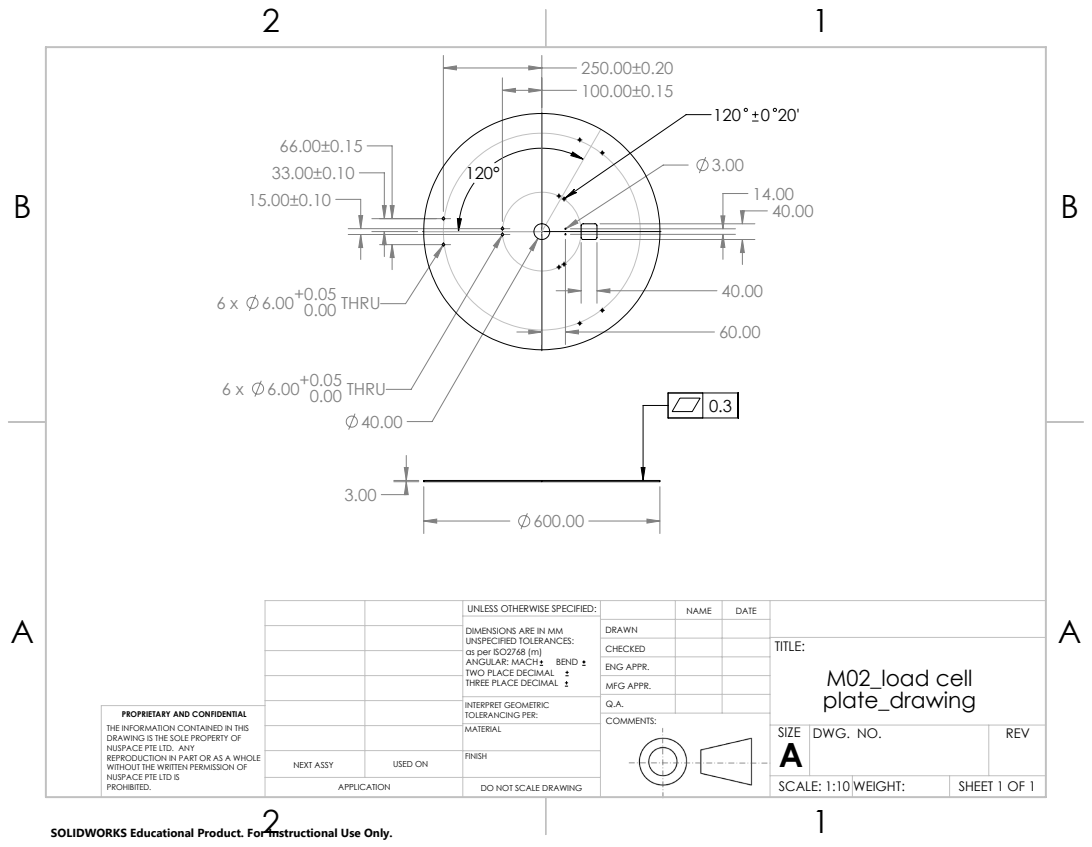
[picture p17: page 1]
6 x 6.00+0.05 0.00 THRU

UNLESS OTHERWISE SPECIFIED: | | NAME | DATE
DIMENSIONS ARE IN MM UNSPECIFIED TOLERANCES: as per ISO2768 (m) ANGULAR: MACH BEND TWO PLACE DECIMAL THREE PLACE DECIMAL | DRAWN

CHECKED | | | TITLE: M02_load cell plate_drawing

ENG APPR.
MFG APPR.

INTERPRET GEOMETRIC TOLERANCING PER: | Q.A.
MATERIAL | | SIZE A | DWG. NO. | REV

PROPRIETARY AND CONFIDENTIAL
THE INFORMATION CONTAINED IN THIS
DRAWING IS THE SOLE PROPERTY OF
NUSPACE PTE LTD. ANY
REPRODUCTION IN PART OR AS A WHOLE
WITHOUT THE WRITTEN PERMISSION OF
NUSPACE PTE LTD IS
PROHIBITED.

NEXT ASSY | USED ON | FINISH

APPLICATION | DO NOT SCALE DRAWING | | SCALE: 1:10 WEIGHT: | | SHEET 1 OF 1

SOLIDWORKS Educational Product. For Instructional Use Only.

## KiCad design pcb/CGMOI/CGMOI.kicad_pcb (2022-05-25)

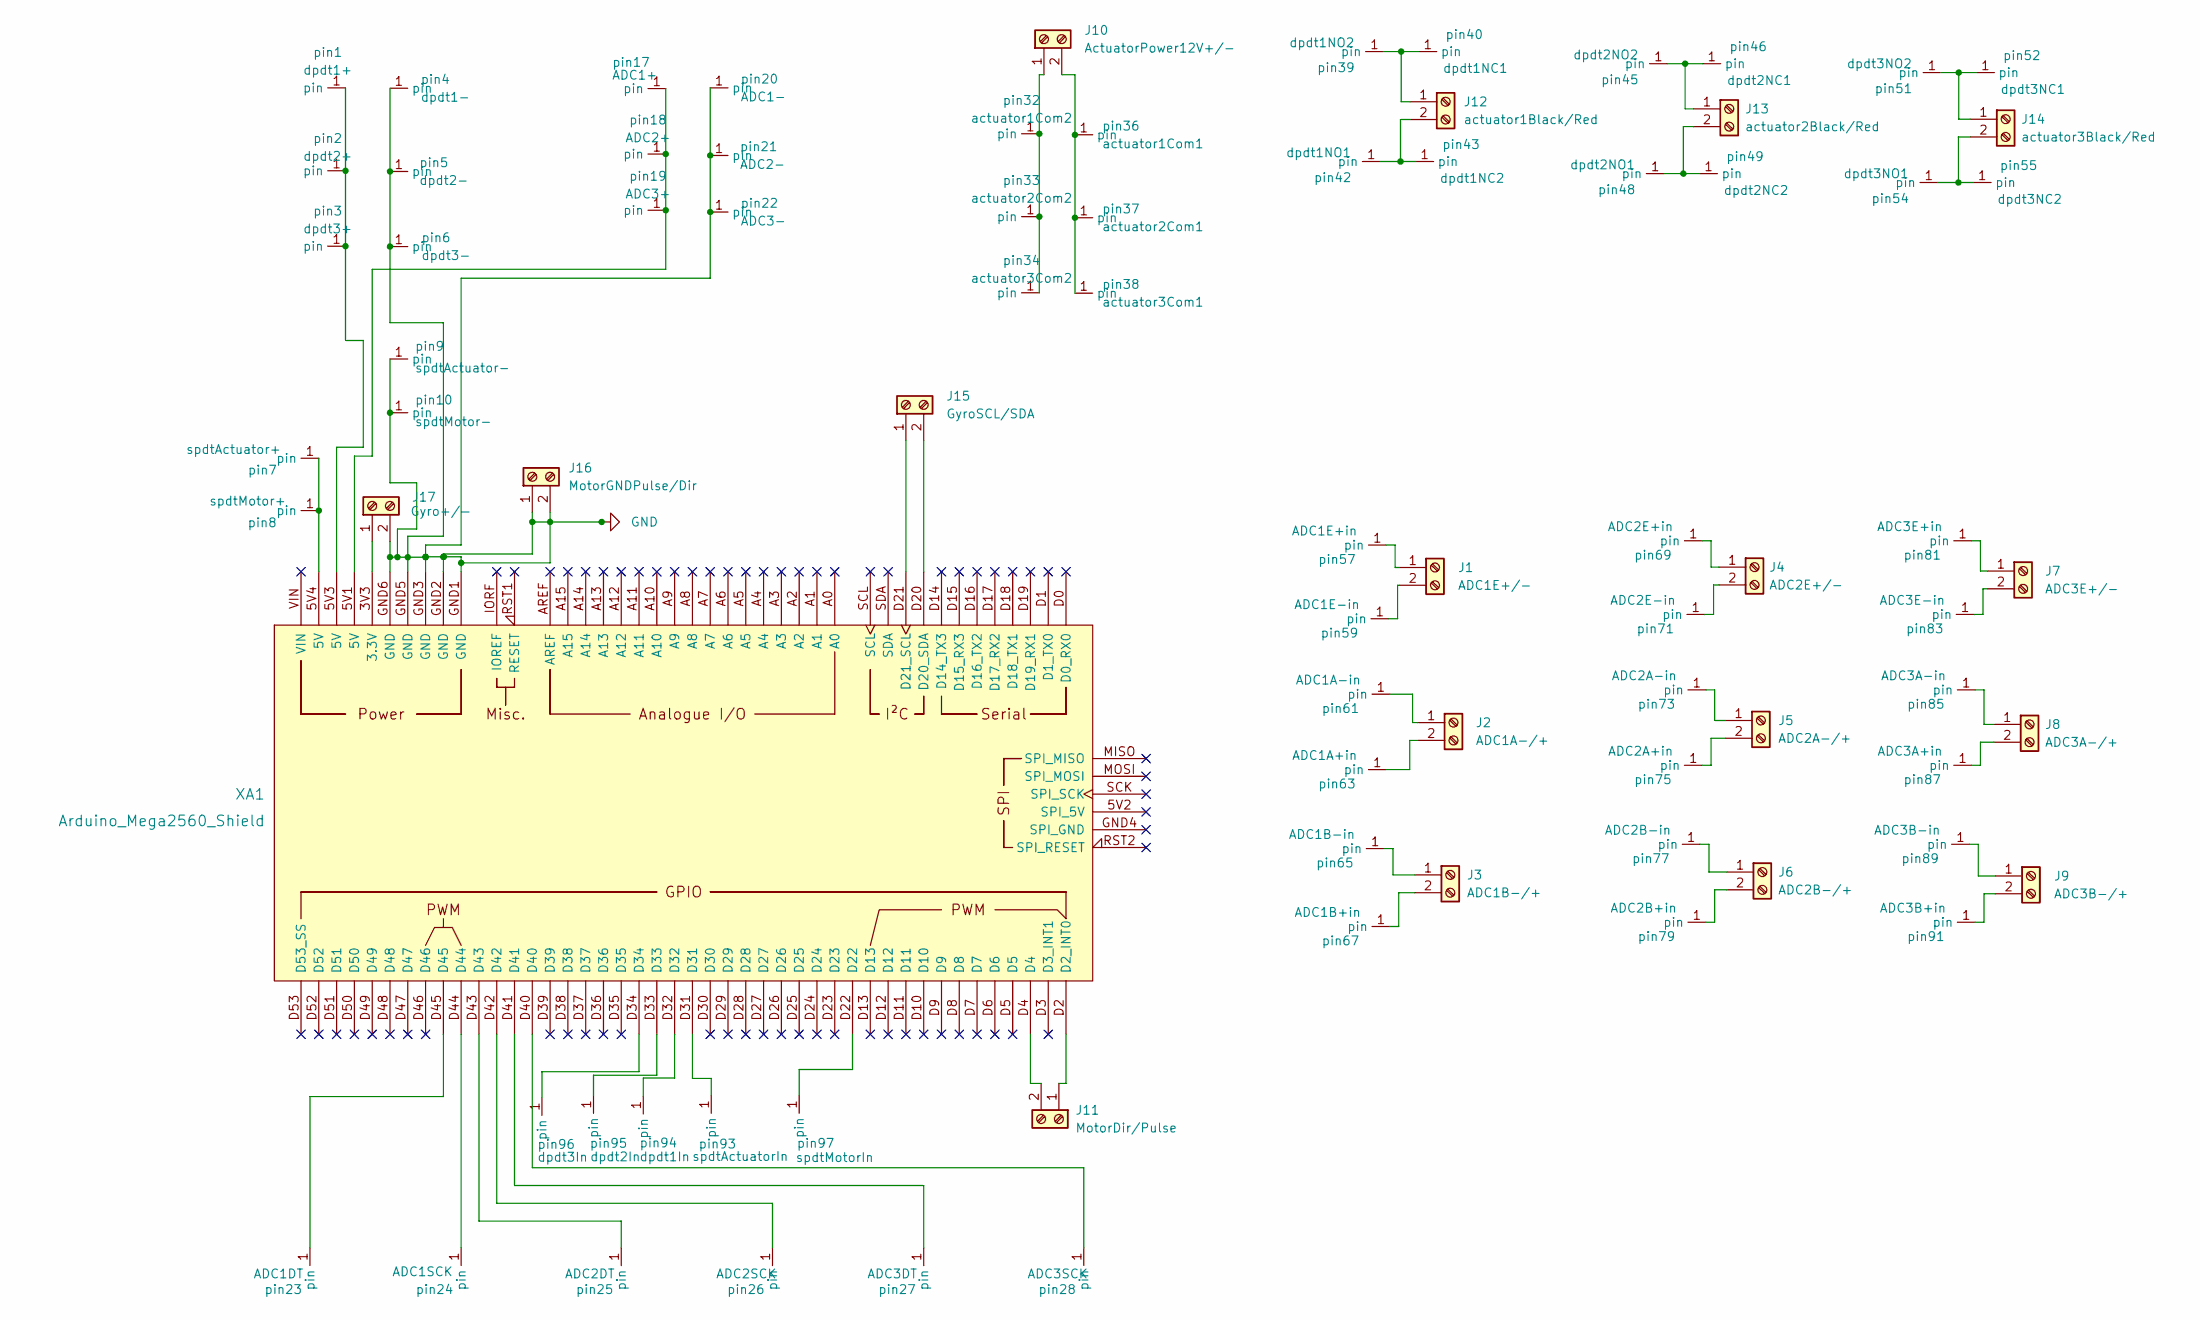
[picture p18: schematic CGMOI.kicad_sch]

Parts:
J1: ADC1E+/-; screw terminal
J2: ADC1A-/+; screw terminal
J3: ADC1B-/+; screw terminal
J4: ADC2E+/-; screw terminal
J5: ADC2A-/+; screw terminal
J6: ADC2B-/+; screw terminal
J7: ADC3E+/-; screw terminal
J8: ADC3A-/+; screw terminal
J9: ADC3B-/+; screw terminal
J10: ActuatorPower12V+/-; screw terminal
J11: MotorDir/Pulse; screw terminal
J12: actuator1Black/Red; screw terminal
J13: actuator2Black/Red; screw terminal
J14: actuator3Black/Red; screw terminal
J15: GyroSCL/SDA; screw terminal
J16: MotorGNDPulse/Dir; screw terminal
J17: Gyro+/-; screw terminal
XA1: Arduino_Mega2560_Shield
pin1: dpdt1+; pin
pin2: dpdt2+; pin
pin3: dpdt3+; pin
pin4: dpdt1-; pin
pin5: dpdt2-; pin
pin6: dpdt3-; pin
pin7: spdtActuator+; pin
pin8: spdtMotor+; pin
pin9: spdtActuator-; pin
pin10: spdtMotor-; pin
pin17: ADC1+; pin
pin18: ADC2+; pin
pin19: ADC3+; pin
pin20: ADC1-; pin
pin21: ADC2-; pin
pin22: ADC3-; pin
pin23: ADC1DT; pin
pin24: ADC1SCK; pin
pin25: ADC2DT; pin
pin26: ADC2SCK; pin
pin27: ADC3DT; pin
pin28: ADC3SCK; pin
pin32: actuator1Com2; pin
pin33: actuator2Com2; pin
pin34: actuator3Com2; pin
pin36: actuator1Com1; pin
pin37: actuator2Com1; pin
pin38: actuator3Com1; pin
pin39: dpdt1NO2; pin
pin40: dpdt1NC1; pin
pin42: dpdt1NO1; pin
pin43: dpdt1NC2; pin
pin45: dpdt2NO2; pin
pin46: dpdt2NC1; pin
pin48: dpdt2NO1; pin
pin49: dpdt2NC2; pin
pin51: dpdt3NO2; pin
pin52: dpdt3NC1; pin
pin54: dpdt3NO1; pin
pin55: dpdt3NC2; pin
pin57: ADC1E+in; pin
pin59: ADC1E-in; pin
pin61: ADC1A-in; pin
pin63: ADC1A+in; pin
pin65: ADC1B-in; pin
pin67: ADC1B+in; pin
pin69: ADC2E+in; pin
pin71: ADC2E-in; pin
pin73: ADC2A-in; pin
pin75: ADC2A+in; pin
pin77: ADC2B-in; pin
pin79: ADC2B+in; pin
pin81: ADC3E+in; pin
pin83: ADC3E-in; pin
pin85: ADC3A-in; pin
pin87: ADC3A+in; pin
pin89: ADC3B-in; pin
pin91: ADC3B+in; pin
pin93: spdtActuatorIn; pin
pin94: dpdt1In; pin
pin95: dpdt2In; pin
pin96: dpdt3In; pin
pin97: spdtMotorIn; pin

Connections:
GND: J16.1, J16.2, J17.2, XA1.GND1 (GND), XA1.GND2 (GND), XA1.GND3 (GND), XA1.GND5 (GND), XA1.GND6 (GND), pin4.1 (pin), pin5.1 (pin), pin6.1 (pin), pin9.1 (pin), pin10.1 (pin), pin20.1 (pin), pin21.1 (pin), pin22.1 (pin)
unnamed: J1.1, pin57.1 (pin)
unnamed: J1.2, pin59.1 (pin)
unnamed: J2.1, pin61.1 (pin)
unnamed: J2.2, pin63.1 (pin)
unnamed: J3.1, pin65.1 (pin)
unnamed: J3.2, pin67.1 (pin)
unnamed: J4.1, pin69.1 (pin)
unnamed: J4.2, pin71.1 (pin)
unnamed: J5.1, pin73.1 (pin)
unnamed: J5.2, pin75.1 (pin)
unnamed: J6.1, pin77.1 (pin)
unnamed: J6.2, pin79.1 (pin)
unnamed: J7.1, pin81.1 (pin)
unnamed: J7.2, pin83.1 (pin)
unnamed: J8.1, pin85.1 (pin)
unnamed: J8.2, pin87.1 (pin)
unnamed: J9.1, pin89.1 (pin)
unnamed: J9.2, pin91.1 (pin)
unnamed: J10.1, pin32.1 (pin), pin33.1 (pin), pin34.1 (pin)
unnamed: J10.2, pin36.1 (pin), pin37.1 (pin), pin38.1 (pin)
unnamed: J11.1, XA1.D2 (D2_INT0)
unnamed: J11.2, XA1.D4
unnamed: J12.1, pin39.1 (pin), pin40.1 (pin)
unnamed: J12.2, pin42.1 (pin), pin43.1 (pin)
unnamed: J13.1, pin45.1 (pin), pin46.1 (pin)
unnamed: J13.2, pin48.1 (pin), pin49.1 (pin)
unnamed: J14.1, pin51.1 (pin), pin52.1 (pin)
unnamed: J14.2, pin54.1 (pin), pin55.1 (pin)
unnamed: J15.1, XA1.D21 (D21_SCL)
unnamed: J15.2, XA1.D20 (D20_SDA)
unnamed: J17.1, XA1.3V3 (3.3V)
unnamed: XA1.5V1 (5V), pin17.1 (pin), pin18.1 (pin), pin19.1 (pin)
unnamed: XA1.5V3 (5V), pin1.1 (pin), pin2.1 (pin), pin3.1 (pin)
unnamed: XA1.5V4 (5V), pin7.1 (pin), pin8.1 (pin)
unnamed: XA1.D22, pin97.1 (pin)
unnamed: XA1.D31, pin93.1 (pin)
unnamed: XA1.D32, pin94.1 (pin)
unnamed: XA1.D33, pin95.1 (pin)
unnamed: XA1.D34, pin96.1 (pin)
unnamed: XA1.D40, pin28.1 (pin)
unnamed: XA1.D41, pin27.1 (pin)
unnamed: XA1.D42, pin26.1 (pin)
unnamed: XA1.D43, pin25.1 (pin)
unnamed: XA1.D44, pin24.1 (pin)
unnamed: XA1.D45, pin23.1 (pin)

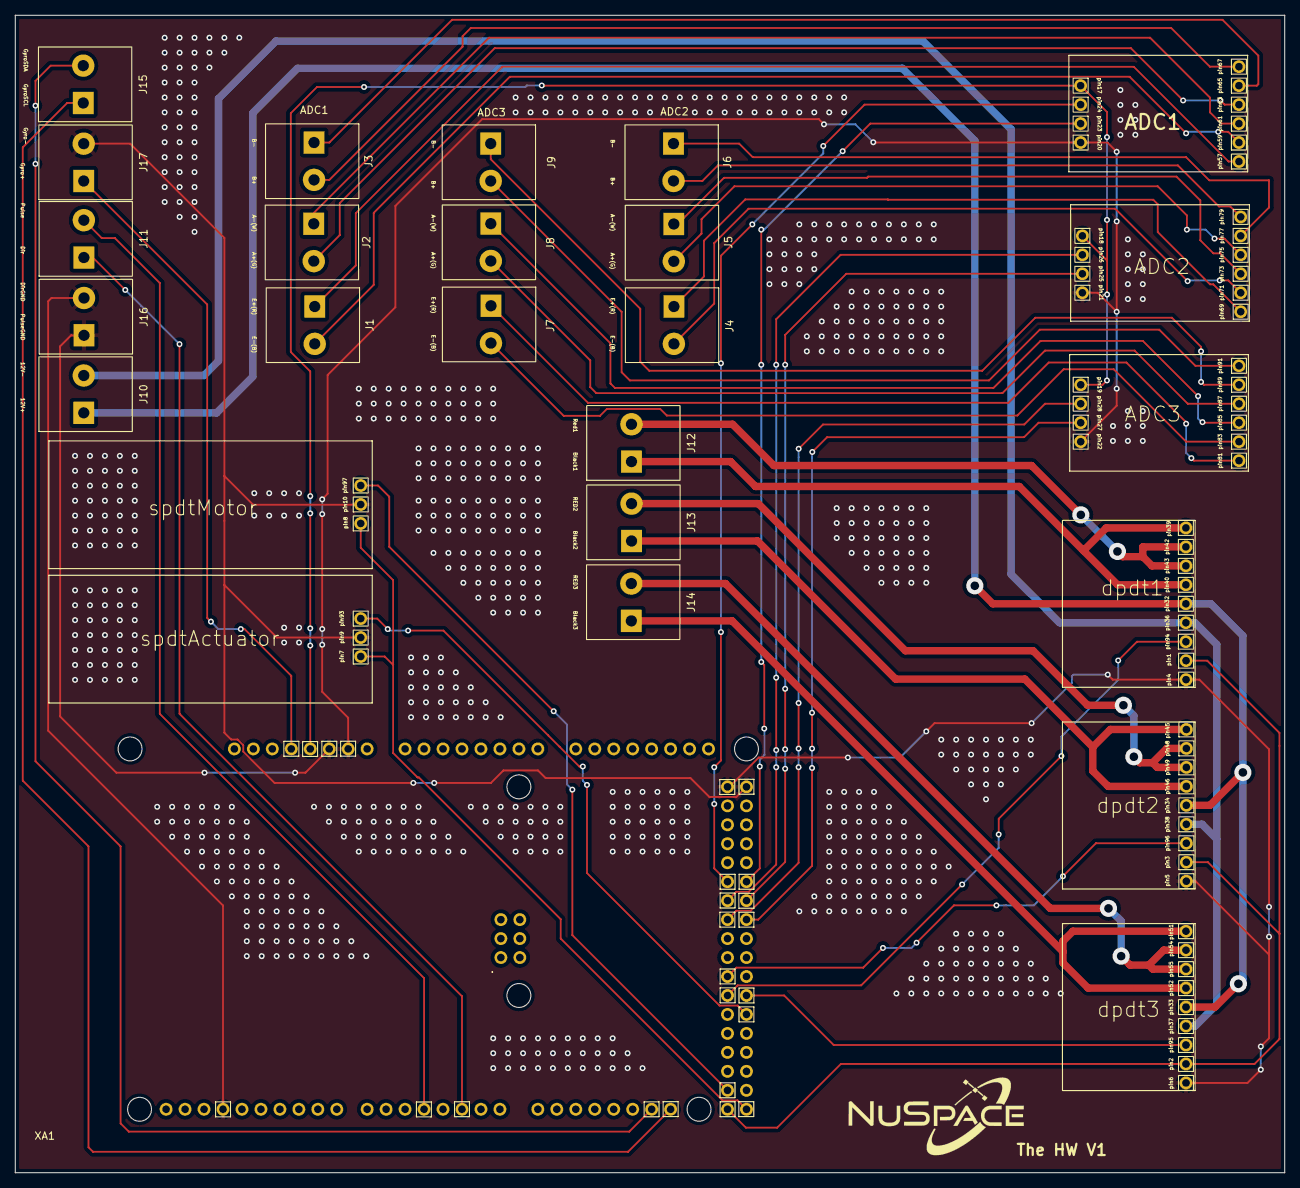
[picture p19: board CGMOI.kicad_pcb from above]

Board: 2 copper layers, 170.0 x 155.0 mm, 81 parts (1 on the bottom side), 46 nets.

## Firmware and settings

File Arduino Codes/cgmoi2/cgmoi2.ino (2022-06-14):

#include <Arduino_FreeRTOS.h> //FreeRTOS library
#include <BMI160Gen.h> //Gyro library
#include <SimpleKalmanFilter.h> //Kalman filter library
#include <AccelStepper.h> //AccelStepper library
#include <HX711_ADC.h> //Load cell library
#if defined(ESP8266)|| defined(ESP32) || defined(AVR)
#endif

//FreeRTOS definitions---------------------------------------------------------------------------
void TaskGyro( void *pvParameters );
void TaskMotor( void *pvParameters );
void TaskCg(void *pvParameters);
void TaskMovePlate(void *pvParameters);

//define task handle
TaskHandle_t Gyro;
TaskHandle_t Motor;
TaskHandle_t Cg;
TaskHandle_t Rotate;

//Gyro definitions--------------------------------------------------------------------------------
const int select_pin = 10;
const int i2c_addr = 0x69;
uint8_t OSR4 = OSR4;

int loopCount = 0; //counting number of times Gyro task loops to get number of readings obtained by readAccelerometer function
float totalAccelDeg = 0;
float avgAccelDeg = 0;
float peakAccel = 0;

int xAccelRawOffset, yAccelRawOffset, zAccelRawOffset; //Raw offset data
int xAccelRaw, yAccelRaw, zAccelRaw; //Raw actual data
float totalYAccelOffset = 0; 
float totalXAccelOffset = 0;

//Step motor definitions----------------------------------------------------------------------------------------------------------------------
// Define stepper motor connections:
#define dirPin 2
#define stepPin 4
#define motorInterfaceType 1
#define stepperMotorSignal 22

// Create new instances of the AccelStepper class---------------------------------------------------------------------------------------------
AccelStepper stepper = AccelStepper(motorInterfaceType, stepPin, dirPin);
AccelStepper rotate = AccelStepper(motorInterfaceType, stepPin, dirPin);

//Load cell definitions----------------------------------------------------------------------------------------------------
//pins:
const int HX711_dout_1 = 45; //mcu > HX711 no 1 dout pin
const int HX711_sck_1 = 44; //mcu > HX711 no 1 sck pin
const int HX711_dout_2 = 43; //mcu > HX711 no 2 dout pin
const int HX711_sck_2 = 42; //mcu > HX711 no 2 sck pin
const int HX711_dout_3 = 41; //mcu > HX711 no 3 dout pin
const int HX711_sck_3 = 40; //mcu > HX711 no 3 sck pin

//HX711 constructor (dout pin, sck pin)
HX711_ADC LoadCell_1(HX711_dout_1, HX711_sck_1); //HX711 1
HX711_ADC LoadCell_2(HX711_dout_2, HX711_sck_2); //HX711 2
HX711_ADC LoadCell_3(HX711_dout_3, HX711_sck_3); //HX711 3
unsigned long t = 0;

//linear actuator definition--------------------------------------------------------------------------------------
int spdtSignal = 31; //power supply
int dpdtSignal1 = 32; //linear actuator 1
int dpdtSignal2 = 34; //linear actuator 2
int dpdtSignal3 = 33; //linear actuator 3

//Define kalman filters---------------------------------------------------------------------------------------------
SimpleKalmanFilter massKalmanFilter(2, 2, 1);
SimpleKalmanFilter xCGKalmanFilter(0.7, 0.7, 0.9);
SimpleKalmanFilter yCGKalmanFilter(0.7, 0.7, 0.9);
SimpleKalmanFilter angularAccelDegFilter(1, 1, 0.5);

void setup() {
  
  Serial.begin(9600);
  while (!Serial);
  
//Set up tasks to run independently----------------------------------------------------------------------------------------
   xTaskCreate(
    TaskCg
    ,  "Cg"
    ,  128
    ,  NULL
    ,  2
    ,  &Cg);  
   
   xTaskCreate(
    TaskMotor
    ,  "Motor"
    ,  128  // Stack size
    ,  NULL
    ,  1  // Priority
    ,  &Motor);
  
  xTaskCreate(
   TaskGyro
   ,  "Gyro"   // A name just for humans
   ,  128  // This stack size can be checked & adjusted by reading the Stack Highwater
   ,  NULL
   ,  1  // Priority, with 3 (configMAX_PRIORITIES - 1) being the highest, and 0 being the lowest.
   ,  &Gyro );

   xTaskCreate(
    TaskRotate
    , "Move"
    , 128
    , NULL
    , 1
    , &Rotate);
   
//Set up Gyro----------------------------------------------------------------------------------------------------
  // initialize device
  BMI160.begin(BMI160GenClass::I2C_MODE, i2c_addr);
  // Set the accelerometer range to 4g
  BMI160.setAccelerometerRange(4);
  //Serial.println("Initializing IMU device...done.");

  //Set digital low pass filter for gyro
  BMI160.setAccelDLPFMode(OSR4);

  //Set sampling rate to 1600Hz
  BMI160.setAccelRate(12);
  
  //Calibrating accelerometer offset
  //Serial.println("Calibrating accelerometer");
  BMI160.autoCalibrateXAccelOffset(0);
  BMI160.setAccelOffsetEnabled(true);
  BMI160.autoCalibrateYAccelOffset(0);
  BMI160.setAccelOffsetEnabled(true);
  //BMI160.autoCalibrateZAccelOffset(-1);
  //BMI160.setAccelOffsetEnabled(true);

  /*//Measure offset values before motor starts
  for (int i = 0; i < 20; i++) { //collect data from accelerometer to calculate offset values
    BMI160.readAccelerometer(xAccelRawOffset, yAccelRawOffset, zAccelRawOffset);
    
    //convert raw data to g
    float xAccelOffset = convertRawGyro(xAccelRawOffset);
    float yAccelOffset = convertRawGyro(yAccelRawOffset);
    float zAccelOffset = convertRawGyro(zAccelRawOffset);
    totalXAccelOffset = totalXAccelOffset + xAccelOffset;
    totalYAccelOffset = totalYAccelOffset + yAccelOffset;
    delay(100);
  }

  float avgXOffset = totalXAccelOffset/20;
  float avgYOffset = totalYAccelOffset/20;
  float netOffset = sqrt(sq(avgXOffset) + sq(avgYOffset));*/
  Serial.println("Gyro start up is complete");

//Set up motor-------------------------------------------------------------------------------------------------------------------
  // Declare pins as output:
  pinMode(stepPin, OUTPUT);
  pinMode(dirPin, OUTPUT);
  pinMode(stepperMotorSignal, OUTPUT);

  // Set the maximum speed and acceleration for stepper and rotate:
  stepper.setMaxSpeed(99999999);
  stepper.setAcceleration(999999);
  rotate.setMaxSpeed(16000);
  rotate.setAcceleration(100);

  //Turn off power to stepper motor
  digitalWrite(stepperMotorSignal, HIGH);
  Serial.println("Motor start up is complete");

//Set up load cell------------------------------------------------------------------------------------------------------
  float calibrationValue_1; // calibration value load cell 1
  float calibrationValue_2; // calibration value load cell 2
  float calibrationValue_3; // calibration value load cell 3
  
  calibrationValue_1 = 88.80; // uncomment this if you want to set this value in the sketch
  calibrationValue_2 = 90.59; // uncomment this if you want to set this value in the sketch
  calibrationValue_3 = 91.09; // uncomment this if you want to set this value in the sketch
  
  LoadCell_1.begin();
  LoadCell_2.begin();
  LoadCell_3.begin();
  
  unsigned long stabilizingtime = 10000; // tare preciscion can be improved by adding a few seconds of stabilizing time
  boolean _tare = true; //set this to false if you don't want tare to be performed in the next step
  byte loadcell_1_rdy = 0;
  byte loadcell_2_rdy = 0;
  byte loadcell_3_rdy = 0;
  while ((loadcell_1_rdy + loadcell_2_rdy + loadcell_3_rdy) < 3) { //run startup, stabilization and tare, both modules simultaniously
    if (!loadcell_1_rdy) loadcell_1_rdy = LoadCell_1.startMultiple(stabilizingtime, _tare);
    if (!loadcell_2_rdy) loadcell_2_rdy = LoadCell_2.startMultiple(stabilizingtime, _tare);
    if (!loadcell_3_rdy) loadcell_3_rdy = LoadCell_3.startMultiple(stabilizingtime, _tare);
  }
  if (LoadCell_1.getTareTimeoutFlag()) {
    Serial.println("Timeout, check MCU>HX711 no.1 wiring and pin designations");
  }
  if (LoadCell_2.getTareTimeoutFlag()) {
    Serial.println("Timeout, check MCU>HX711 no.2 wiring and pin designations");
  }
  if (LoadCell_3.getTareTimeoutFlag()) {
    Serial.println("Timeout, check MCU>HX711 no.3 wiring and pin designations");
  }
  LoadCell_1.setCalFactor(calibrationValue_1); // user set calibration value (float)
  LoadCell_2.setCalFactor(calibrationValue_2); // user set calibration value (float)
  LoadCell_3.setCalFactor(calibrationValue_2); // user set calibration value (float)
  Serial.println("Load cell Startup is complete");

//Linear actuator set up---------------------------------------------------------------------------------------------------------------
  // Set pins as an output pin
  pinMode(spdtSignal, OUTPUT);
  pinMode(dpdtSignal1, OUTPUT);
  pinMode(dpdtSignal2, OUTPUT);
  pinMode(dpdtSignal3, OUTPUT);

  digitalWrite(spdtSignal, HIGH); //turn off power to linear actuators
  Serial.println("Linear actuator start up is complete");

  Serial.println("Set up finish");
  Serial.println("MODE CG");

  //first suspend Rotate, Gyro and Motor tasks and turn off power to motor   
  vTaskSuspend(Gyro);    
  digitalWrite(stepperMotorSignal, HIGH);
  vTaskSuspend(Motor);
  vTaskSuspend(Rotate);
  
  Serial.println("Suspend rotate, motor and gyro tasks, ready for input");
  
}

void loop() {
//nothing in loop
}

//Gyro task-----------------------------------------------------------------------------------------------------------------
void TaskGyro(void *pvParameters) {
  (void) pvParameters;

  for (;;) {
    if (loopCount < 30) { //By limitting loopCount, gyro only record during acceleration process and neglecting the deceleration process
      // add 1 to loop count everytime loop happens
      loopCount = loopCount + 1;
      //Serial.print("loop: ");
      //Serial.println(loopCount);
    
      BMI160.readAccelerometer(xAccelRaw, yAccelRaw, zAccelRaw);

      //convert raw data to g
      float xAccel = convertRawGyro(xAccelRaw);
      float yAccel = convertRawGyro(yAccelRaw);

      float netAccel = sqrt(sq(xAccel) + sq(yAccel)); // net acceleration
      //netAccel = netAccel; //Minus off offset value
      float angularAccelRad = (netAccel * 9.807)/0.185; //angular acceleration is acceleration in g converted to m/s^2 divided by radius(dist from chip to center of top plate)
      //Serial.println(angularAccelRad);
      float angularAccelDeg = (angularAccelRad/3.14159265359)*180;

      //Run value through Kalman filter
      angularAccelDeg = angularAccelDegFilter.updateEstimate(angularAccelDeg);
  
      //Serial.println(angularAccelDeg);
 
      /*//add angularAccelDeg to total tally 
      totalAccelDeg = totalAccelDeg + angularAccelDeg;
      //avgAccelDeg = totalAccelDeg / loopCount;
      //Serial.println(avgAccelDeg);*/
  
      //get peak acceleration
      if (angularAccelDeg > peakAccel) {
        peakAccel = angularAccelDeg;
      }
      
      vTaskDelay(1);
    }

    else {
      vTaskDelay(1);
    }
  }
}

//Motor task----------------------------------------------------------------------------------------------------------
void TaskMotor(void *pvParameters) {
  (void) pvParameters;

  for (;;) {
    float rslts[10]; //array of 10 peak values from 10 measurements
    //Serial.println("Recording in progress...");

    //Record 10 values and add to rslts array. Since first recording tends to be inaccurate, i is set to 11 to so that the first reading is not added to array
    for (int i = 0; i < 11; i++) {
   
      // Set the target position:
      stepper.moveTo(4000);
      //Serial.println("set move to position");
    
      //resume Gyro task
      Serial.println("resume gyro");
      vTaskResume(Gyro);
           
      //Run to target position with set speed and acceleration/deceleration:
      stepper.runToPosition();

      //suspend Gyro task
      vTaskSuspend(Gyro);
      Serial.println("suspend gyro");
      
      //get average acceleration
      avgAccelDeg = totalAccelDeg / 30;

      //print average accel
      Serial.print("peak acceleration: ");
      Serial.println(peakAccel);

      //add only the second value onwards to array
      if (i > 0) {
        rslts[i-1] = peakAccel;
        }
      
      vTaskDelay(1000/portTICK_PERIOD_MS);

      // Move back to zero:
      stepper.moveTo(0);
      stepper.runToPosition();
      //Serial.println("back to origin");

      vTaskDelay(1000/portTICK_PERIOD_MS);

      //reset values to 0
      loopCount = 0;
      peakAccel = 0;
      avgAccelDeg = 0;
      totalAccelDeg = 0;
      //Serial.print("reset");   
    }

    //Calculate mean value from array
    
    float totaccelarray = 0;
    float meanaccelarray = 0;
    for (int y = 0; y < 10; y++) {
      totaccelarray = totaccelarray + rslts[y];
      //Serial.println(rslts[y]);
    }
    meanaccelarray = totaccelarray/10;
    Serial.print("Mean: ");
    Serial.println(meanaccelarray);

    Serial.println("Finish recording");
    Serial.println("15 seconds until recording resumes");
    vTaskDelay(15000/portTICK_PERIOD_MS);


    //receive command from serial monitor
    if (Serial.available() > 0) {
      int incomingByte = Serial.parseInt();

      //send "12" to turn on power to stepper motor
      if (incomingByte == 12) {
        digitalWrite(stepperMotorSignal, LOW);
        Serial.println("Stepper Motor power on"); 
       }

      //send "13" to turn off power to stepper motor
      else if (incomingByte == 13) { 
         digitalWrite(stepperMotorSignal, HIGH);
         Serial.println("Stepper Motor power off");
      }

      //send "15" to suspend Gyro and Motor tasks and resume cg task
      else if (incomingByte == 15) { 
        Serial.println("Suspend gyro and motor, resume Cg");
        Serial.println("MODE CG");
        vTaskSuspend(Gyro);
        digitalWrite(stepperMotorSignal, HIGH); //turn off power to stepper motor
        vTaskResume(Cg);
        vTaskSuspend(Motor);
      }

      //send "16" to suspend Gyro and Motor tasks and resume/start Rotate
      else if (incomingByte == 16) {
        digitalWrite(stepperMotorSignal, HIGH); //turn off power to stepper motor
        
        Serial.println("Suspend Cg, start/resume Rotate");
        Serial.println("MODE ROTATE");
        Serial.println("Input steps.");
        Serial.println("Positive = clockwise from origin, negative = counter clockewise from origin.");
        

        vTaskResume(Rotate);
        vTaskSuspend(Motor);
      }
    }
  }
}

//Rotate task----------------------------------------------------------------------------------------------------------------------------
void TaskRotate(void *pvParameters) {
  (void) pvParameters;

  for (;;){
      if (Serial.available() > 0) {
    
      int incomingByte = Serial.parseInt();

      if (incomingByte < 20 && incomingByte > 0) {
        //send "12" to turn on power to stepper motor
        if (incomingByte == 12) { 
        digitalWrite(stepperMotorSignal, LOW);
        Serial.println("Stepper Motor power on"); 
       }

        //send "13" to turn off power to stepper motor
        else if (incomingByte == 13) { 
           digitalWrite(stepperMotorSignal, HIGH);
           Serial.println("Stepper Motor power off");
        }

        //Send "14" to suspend Rotate task and resume/start Motor and Gyro tasks
        if (incomingByte == 14) { 
          Serial.println("Suspend Cg, start/resume motor and gyro");
          Serial.println("MODE MOI");
          digitalWrite(stepperMotorSignal, LOW); //turn on power to motor
          
          vTaskResume(Motor);
          //TaskResume(Gyro);     
          vTaskSuspend(Rotate);
        }

        //Send "15 to suspend Rotate task and resume Cg task
        if (incomingByte == 15) {
          Serial.println("Suspend Rotate, resume Cg");
          Serial.println("MODE CG");
          //Turn off power to stepper motor
          digitalWrite(stepperMotorSignal, HIGH);
          vTaskResume(Cg);
          vTaskSuspend(Rotate);
        }
      }

      else { //send number of steps to rotate
  
        //Turn on power to stepper motor (LOW = on, HIGH = off)
        digitalWrite(stepperMotorSignal, LOW);
    
        // Set the target position(positive = cw, negative = ccw)
        rotate.moveTo(incomingByte);
        //Run to target position with set speed and acceleration/deceleration:
        rotate.runToPosition();
    
        Serial.print("Position ");
        Serial.print(incomingByte);
        Serial.println(" reached");
    
        //Turn off power to stepper motor (LOW = on, HIGH = off)
        digitalWrite(stepperMotorSignal, HIGH);
      }
    }
  }
}
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

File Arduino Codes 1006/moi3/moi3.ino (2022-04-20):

#include <BMI160Gen.h> //Gyro library
#include <SimpleKalmanFilter.h> //Kalman filter library

//Gyro definitions--------------------------------------------------------------------------------
const int select_pin = 10;
const int i2c_addr = 0x69;
uint8_t OSR4 = OSR4;

//define Kalman filter
SimpleKalmanFilter simpleKalmanFilter(13, 13, 0.7);

//Step motor definitions-----------------------------------------------------------------------------
// Define stepper motor connections:
#define dirPin 2
#define stepPin 4
#define stepperMotorSignal 22

void setup() {
//Set up Gyro----------------------------------------------------------------------------------------------------
  Serial.begin(9600); // initialize Serial communication
  while (!Serial);    // wait for the serial port to open

  // initialize device
  BMI160.begin(BMI160GenClass::I2C_MODE, i2c_addr);
  // Set the accelerometer range to 4g
  BMI160.setAccelerometerRange(4);
  Serial.println("Initializing IMU device...done.");

  //Set filter for gyro
  BMI160.setAccelDLPFMode(OSR4);

  //Set sampling rate to 1600Hz
  BMI160.setAccelRate(12);

  //Calibrating accelerometer offset
  Serial.println("Calibrating accelerometer");
  BMI160.autoCalibrateXAccelOffset(0);
  BMI160.setAccelOffsetEnabled(true);
  BMI160.autoCalibrateYAccelOffset(0);
  BMI160.setAccelOffsetEnabled(true);
  //BMI160.autoCalibrateZAccelOffset(-1);
  //BMI160.setAccelOffsetEnabled(true);
  delay(1000);
  
  delay(500);
  Serial.println("Accelerometer offset enabled");

//Set up motor------------------------------------------------------------------------------
  // Declare pins as output:
  pinMode(stepPin, OUTPUT);
  pinMode(dirPin, OUTPUT);
  pinMode(stepperMotorSignal, OUTPUT);

  //change pwm frequency
  TCCR5B = TCCR5B & B11111000 | B00000001;  // for PWM frequency of 31372.55 Hz
  
  // Set the spinning direction to CCW:
  //digitalWrite(dirPin, LOW);

  //Turn off power to stepper motor
  digitalWrite(stepperMotorSignal, HIGH);
}

void loop() {
  //Turn on power to stepper motor
  digitalWrite(stepperMotorSignal, LOW);
  
  //Set the spinning direction to CW
  digitalWrite(dirPin, HIGH);
  
  //Variables for Gyro readings
  int xAccelRawOffset, yAccelRawOffset, zAccelRawOffset; //Raw offset data
  int xAccelRaw, yAccelRaw, zAccelRaw; //Raw actual data
  float totalYAccelOffset = 0; 
  float totalXAccelOffset = 0;
  float totalYAccel = 0;
  float totalXAccel = 0;
  float rslts[10]; //array of 10 peak values from 10 measurements

  
  //Measure offset values before motor starts
  for (int i = 0; i < 20; i++) { //collect data from accelerometer to calculate offset values
    BMI160.readAccelerometer(xAccelRawOffset, yAccelRawOffset, zAccelRawOffset);
    
    //convert raw data to g
    float xAccelOffset = convertRawGyro(xAccelRawOffset);
    float yAccelOffset = convertRawGyro(yAccelRawOffset);
    float zAccelOffset = convertRawGyro(zAccelRawOffset);
    //Serial.println("OFFSET VALUES");
    //Serial.print(xAccelOffset);Serial.print("\t");
    //Serial.print(yAccelOffset);Serial.print("\t");
    //Serial.print(zAccelOffset);Serial.print("\t");
    //Serial.println();
    totalXAccelOffset = totalXAccelOffset + xAccelOffset;
    totalYAccelOffset = totalYAccelOffset + yAccelOffset;
    //Serial.print("total accel offset(x,y): ");
    //Serial.print(totalXAccelOffset);Serial.print("\t");
    //Serial.println(totalYAccelOffset);
    delay(200);
  }

  //Serial.print("total accel offset(x,y): ");
  //Serial.print(totalXAccelOffset);Serial.print("\t");
  //Serial.println(totalYAccelOffset);
  
  delay(10);

  for (int x = 0; x < 10; x++) {//Run 10 times to collect 10 peak values for rslts array
    float peakValue = 0; //peak value of one measurement

    
    digitalWrite(dirPin, HIGH); //Set spinning direction to CW   
    analogWrite(stepPin,127); //Run stepper motor

    //Measure actual values when as soon as motor starts
    for (int i = 0; i < 800; i++) { //collect data from accelerometer
      BMI160.readAccelerometer(xAccelRaw, yAccelRaw, zAccelRaw);
    
      //convert raw data to g
      float xAccel = convertRawGyro(xAccelRaw);
      float yAccel = convertRawGyro(yAccelRaw);
      //Serial.println("MEASURED VALUES");
      //Serial.println(xAccel);Serial.print("\t");
      //Serial.print(yAccel);Serial.print("\t");  
      //Serial.println();
      //Calculate required values
      float avgXAccel = xAccel - (totalXAccelOffset/20); //average acceleration along x-axis after offset
      float avgYAccel = yAccel - (totalYAccelOffset/20); //average acceleration along y-axis after offset

      //Serial.println(avgYAccel*100);
      
      float netAccel = sqrt(sq(avgXAccel) + sq(avgYAccel)); // net acceleration

      float angularAccelRad = (netAccel * 9.807)/0.185; //angular acceleration is acceleration in g converted to m/s^2 divided by radius(dist from chip to center of top plate)

      float angularAccelDeg = (angularAccelRad/3.14159265359)*180;
  
      //Serial.println(angularAccelDeg);

      //Finding peak value
      if (peakValue < angularAccelDeg) {
        peakValue = angularAccelDeg;
      }
  
    }

    delay(5);
   
    analogWrite(stepPin,0); //turn off motor

    //Run peak value through Kalman filter
    peakValue = simpleKalmanFilter.updateEstimate(peakValue);
    
    Serial.print("Peak angular acceleration: ");
    Serial.println(peakValue);

    rslts[x] = peakValue;
  
    //reverse motor spinning direction and move motor back to starting position
    delay(1000);
    digitalWrite(dirPin, LOW); //Set spinning direction to CCW
    analogWrite(stepPin,127); //Run stepper motor
    delay(975);
    analogWrite(stepPin, 0); //Turn off motor
    delay(1500);

  }

  //turn off power to stepper motor
  digitalWrite(stepperMotorSignal, HIGH);

  //Calculating mean peak value
  float totalPeakValue = 0;
  float meanPeakValue = 0;
  for (int y = 0; y < 10; y++) {
    //Serial.println(rslts[y]);
    totalPeakValue = totalPeakValue + rslts[y]; 
  }
  meanPeakValue = totalPeakValue/10;
  Serial.print("Mean: ");
  Serial.println(meanPeakValue);

  //Calculate standard deviation
  float sqDiffToMean = 0;
  float sumOfDiff = 0;
  float stanDev = 0;
  for (int z = 0; z < 10; z++) {
    sqDiffToMean = sq(meanPeakValue - rslts[z]);
    sumOfDiff =  sumOfDiff + sqDiffToMean;   
  }
  stanDev = sqrt(sumOfDiff/10);
  Serial.print("Standard deviation: ");
  Serial.println(stanDev);
  
  //Serial.println("End of recording");
  delay(10000);

  //Receive command from serial terminal
  if (Serial.available() > 0) {
    int incomingByte = Serial.parseInt();

    if (incomingByte == 12) { //send "12" to turn on power to stepper motor
     digitalWrite(stepperMotorSignal, LOW);
     Serial.println("Stepper Motor power on"); 
    }

    else if (incomingByte == 13) { //send "13" to turn off power to stepper motor
      digitalWrite(stepperMotorSignal, HIGH);
      Serial.println("Stepper Motor power off");
    }
  } 
}
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

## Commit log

2022-04-07 Create Arduino Codes
2022-04-14 stepper motor commands
2022-04-27 read me linear actuator
2022-04-27 readme stepper motor
2022-05-04 screw securing shaft pic
2022-05-04 readme screw securing removeable shaft pic
2022-05-12 satellite mounted picture
2022-05-12 readme mounted satellite pic
2022-05-18 readme pcb section
2022-05-23 new screw terminal link in readme
2022-05-24 pcb 2405
    [CGMOI.kicad_pcb, CGMOI.kicad_sch]
2022-05-24 top plate moi pic
2022-05-24 readme top plate moi pic
2022-05-24 moi top plate pic with arrow
2022-05-25 final pcb with gerbe file
    [CGMOI-B_Cu.gbl, CGMOI-B_Mask.gbs, CGMOI-B_Paste.gbp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]
2022-05-26 readme pcb components
2022-05-26 readme flow chart
2022-05-27 load cell and load cell plate drawing
2022-05-27 gyro pic
2022-05-30 load cell screw pic and readme cgmoi component pics
2022-06-03 read me pcb updates
2022-06-08 readme stuttering actuators solved
2022-06-08 pcb cad link
2022-06-08 power supply pic
2022-06-08 readme power supply pic
2022-06-08 pcb pic
2022-06-08 readme pcb pic
2022-06-09 arduino codes 0906
2022-06-14 arduino codes 1406
